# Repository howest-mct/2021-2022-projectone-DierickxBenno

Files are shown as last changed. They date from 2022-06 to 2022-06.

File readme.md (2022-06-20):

# ***Project One - DogBit***

# **Inhoud**

# Getting things ready for Project One 🎉 🎊

- ### Getting things ready for Project One 🎉 🎊

  - ### Installation

    - ### Downloading the image ⏳
    - ### Restoring the image ⏳
    - ### Linking the RasPi
    - ### Preparing raspi for further use

  - ### Configuration

    - ### ⚠ Do it yourself: Provide WiFi access on the RasPi for home use:
    - ### Already done: Full update/upgrade on 5 May 2022, if you want to upgrade, please
    - ### follow the list below:
    - ### Already done: Installing Apache
    - ### Already done: MariaDB

      - ### Already done: Installing MariaDB
      - ### Already done: Securing MariaDB
      - ### Already done: Create MariaDB User

    - ### ⚠ Do it yourself: Configure MySQLWorkbench
    - ### ⚠ Do it yourself: Configure Visual Studio :
    - ### ⚠ do it yourself: GitHub repo cloning:
    - ### Already done: Python ready:
    - ### Already done: Database import:
    - ### Already done: Chromium kiosk:
    - ### ⚠ do it yourself: run app.py:
    - ### ⚠ do it yourself: display front end in Apache.
    - ### ⚠ Do it yourself: When your project is finished, start automatically.

- ### Good luck!
- ### Demo project

# Installation

> During this installation you will download, install and configure the image for ProjectOne. After
> this, you will configure a preinstalled project so that you have a fully functioning front-end and
> backend at the end.

## Downloading the image ⏳

- Download [project_one.img.zip](https://studenthowest-my.sharepoint.com/:u:/g/personal/pieter-jan_beeckman2_howest_be/EZJTscmkyydAj-VcWTAYtjsBiidK5Grxy54ltO-FoOeE2w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)
  to your local computer.

## Restoring the image ⏳

- ### ⚠ Unzip the file ⚠
- ### Place the file on an SD card of at least 8GB with Win32 Imager or Balena Etcher.
- ### After the image is written, you can remove the SD card and insert it into your RasPi.

## Connecting RasPi

- ### Boot your RasPi.
- ### Connect the RasPi to your computer with a network cable and make an SSH connection in Putty. to 192.168.169 for the user student with password W8w00rd.

> ATTENTION: The image has been created in AZERTY (as opposed to Sensors & Interfacing!)
> Should you have trouble logging in, try in qwerty Z! zààrd.

## Preparing raspi for further use

- ### After logging in, tap sudo raspi-config.
- ### In the menu choose (6) Advanced > (1) Expand Filesystem
- ### ⚠ REBOOT de Raspi

> ⚠ ATTENTION: All buses are still deactivated. Do not forget to activate them via raspi- config

# Configuration

## ⚠ Do it yourself: Provide WiFi access on the RasPi for home use:

- sudo -i to get administrator rights

- `wpa_passphrase <your_SSID@Home> <your_wifi password> >> /etc/wpa_supplicant/wpa_supplicant.conf`
  Replace <your_SSID@Home> with the name of your home network and <your_wifi password>
  with the corresponding password.
- wpa_cli -i wlan0 reconfigure to reload your wireless network card in the RasPi.
- wget [http://www.google.com](http://www.google.com) to see if the wireless internet works.

## Already done: Full update/upgrade on 5 May 2022, if you want to upgrade, please follow the list below:

- apt update to check which updates are available.
  (you still have sudo rights from the previous step, so no need to set sudo)
- apt upgrade to install the available updates.
- Y if you are asked if you are sure.
- Waiting, waiting, waiting, ...

## Already done: Install Apache

- apt install apache2 -y to install Apache, the web server. This package takes over for Full Stack
  Web Developlent / ProjectOne from the Live Server in Visual Studio Code.
- As we are working with Github in this exercise we will make it easy for ourselves by
  put all the material in one folder, both front-end and back-end, as we are used to doing in the
  Full Stack Web Development lessons. For this we will have to change Apache's default folder,
  along with the folder and file permissions, but we will only do this once we have created our
  folder structure.

## Already done: MariaDB

### **Already done: Installing MariaDB**

- apt install mariadb-server mariadb-client -y to install MariaDB, the fork of MySQL

### **Already done: Securing MariaDB**

- mysql_secure_installation to better secure the MariaDB
- First you are asked to enter the current root password for MariaDB. Since there is none yet, you
  can just press Enter here.
- Then you can change the password. Choose a password that you can remember! By default, the
  password chosen here is W8w00rd
- The next step is to delete anonymous users. Choose y here
- Prohibit root from logging in remotely. Choose y here.
- Then remove test database and access? Choose y.
- Finally, reload privilege databases: y

### **Already done: Create MariaDB User**

- Next, we configure the user student with password W8w00rd on the MariaDB server.
- mysql -u root -p to access the MariaDB server^
- grant all on `*.*` to `'student'@'localhost'` identified by `'W8w00rd'`; grant grant option on
  `*.*` to `'student'@'localhost'`; Creates a new user _student_ with password _W8w00rd_ who gets rights to all databases.
- `flush privileges` Reloads privileges
- `exit` exits from the MariaDB server

## ⚠ Do it yourself: Configure MySQLWorkbench

- ### Start MySQLWorkBench on your laptop
- ### Create a new connection.
  - ### Under Connection Method, select Standard TCP/IP over SSH.
  - ### SSH Hostname: 192.168.168.
  - ### SSH Username: student
  - ### SSH Password: W8w00rd
  - ### Save this if possible.
  - ### MySQL Hostname: 127.0.0.
  - ### MySQL Server Port: 3306
  - ### Username: student
  - ### Password: W8w00rd Save this if possible.

## ⚠ Do it yourself: Configure Visual Studio:

- Open Visual Studio
- Install the extension Remote-SSH
- Press F1 and tap SSH. Select the option Remote-SSH: Add New SSH Host
- Tap ssh student@192.168.168.169 - A
- Choose a way to save the file.
- Press F1 and tap SSH. Select the option Remote-SSH: Connect To Host
- Choose the option 192.168.
- A new window will open and the password for the RasPi will be requested.
- Type W8w00rd
- After this Visual Studio Codede connection will open and install a number of things on the RasPi.
  > Be patient. It takes a little longer the first time.

## ⚠ do it yourself: GitHub repo cloning:

- Press the Source Control logo on the left and choose Clone Repository.
- Go to the GitHub Classroom [https://classroom.github.com/a/F6MHgLx-] in a browser and
  accept the invitation. Refresh the page and go to the repo you created. Click the Code
  button and copy the git link.
- Paste the copied link into Visual Studio Code and press enter.
- Place the repo in the /home/student/ folder.
- Visual Studio Code will then ask to open this repo, click Yes
- Then open the file Code/Backend/app.py and give Visual Studio Code some time to load all the
  necessary things.

## Already done: Python ready:

- Before we can run the app.py we need to install some packages for python.
- We are NOT using venv here on the RasPi. Open a Terminal and type the following code:
  - pip install flask-cors
  - pip install flask-socketio
  - pip install mysql-connector-python
  - pip install gevent
  - pip install gevent-websocket
- There **_might_** be an easier way to do this with python

## Already done: Database import:

- Import the database into MariaDB via MySQLWorkbench.

## Already done: Chromium kiosk:

- We can make chrome start up by itself, but to do this we need to install a few pieces of software:

  - `pip install selenium`
  - `sudo apt install chromium-chromedriver`

- With selenium we can control the chrome browser (clicks, tab changes, text input), ...

## ⚠ do it yourself: run app.py:

- Try to run app.py. If you can't press Play (the green triangle) in the window, look in the extensions
  under the Python extension and click install on 192.168.168.169 and wait. Reload if asked.
- If all went well, the backend should now be running.

## ⚠ do it yourself: display front end in Apache.

- Surf on your PC to http://192.168.168.169.

- Normally, you should now see the Apache2 Debian Default Page , which is the default Apache
  page currently located in the /var/www/html/ folder on the RasPi. We will not use this default
  folder, but will use the front-end folder from the repo you just cloned.

- If you are no longer sudo: sudo -i

- `nano /etc/apache2/sites-available/000-default.conf`

- Use down arrow to go to the line where it now says _DocumentRoot /var/www/html_
  or _DocumentRoot /home/student/<name_of_your_repo>/front-end_ and change it to _DocumentRoot
  /home/student/<name_of_your_repo>/front-end_
- Save by doing _Ctrl + x_ , followed by Y and _Enter_
- Then we restart Apache by doing `service apache2 restart`
- Now we have to set the permissions on the root folder correctly.

  - Open nano /etc/apache2/apache2.conf and use the down arrow to look for the following
    lines:

    > ```
    >  <Directory />
    >  Options FollowSymLinks
    >  AllowOverride All
    >  Require all denied
    >  </Directory>.
    > ```

    and change it to:

    > ```
    > <Directory />
    > Options Indexes FollowSymLinks Includes ExecCGI
    > AllowOverride All
    > Require all granted
    > </Directory>.
    > ```

  - Save by doing _trl + x_ , followed by Y and _Enter_

  - Then restart Apache by doing service `apache2 restart`

  - Check if apache is started correctly: `service apache2 status`.
    You should get approximately the following output:

  > Loaded: loaded (/lib/systemd/system/apache2.service; enabled; vendor preset:
  > enabled)
  > Active: active (running) since ...

## ⚠ Do it yourself: When your project is finished, start automatically.

- Create a file called myproject.service
- Place the following code in the file:

  ```
  [Unit]
  Description=ProjectOne Project
  After=network.target
  [Service]
  ExecStart=/usr/bin/python3 -u /home/student/<name_of_your_repo>/backend/app.py

  WorkingDirectory=/home/student/<name_of_your_repo>/backend
  StandardOutput=inherit
  StandardError=inherit
  Restart=always
  User=student
  [Install].
  WantedBy=multi-user.target
  ```

- Copy this file as root user to `/etc/systemd/system` with the command `sudo cp myproject.service/etc/systemd/system/myproject.service`
- Now you can test the file by starting it: sudo systemctl start myproject.service
- Stopping the file can be done by entering the command: sudo systemctl stop myproject.service
- If everything works well you can have the script start automatically after booting: `sudo systemctl enable myproject.service`
- The logs / console output can be seen via `journalctl -u myproject.service`

## Good luck!

> If everything works out, don't forget to take a selfie and submit it to the appropriate assignment!

# Demo project

The image shows an example project where we link a button and LED in real time to the website
and database

- First follow the steps in Installation and Configuration
- Connect a button to pin 20 (use safety resistor)
- Also connect a LED to pin 21 (don't forget its resistor)
- Start via terminal backend:
  > ```
  > cd ~/projectone-demo/backend/
  > python app.py
  > ```
- We will skip apache for a while and will also use python to serve the front-end. In a second
  terminal:
  > ```
  > cd ~/projectone-demo/front-end/
  > python -m http.server
  > ```
- Now you can go to http://192.168.168.169:8000

- The idea now is to get this code into your own repo
- So make sure that your own repo is cloned in `/home/student/<name_of_your_repo>`.

- We will copy the files to our repo:

  > `cp -r ~/projectone-demo/* /home/student/<name_of_your_repo>/`

      - So in my case this is `cp -r ~/projectone-demo/* /home/student/2021-2022-projectone-fgmnts/`

- When you have done this, make sure that apache is configured to display the front-end. The
backend code can be executed manually during development, but for production make sure
the code is started automatically via the service

- Make sure you commit and push your new code, this is the command for the kickoff on 20/

# **Instructables**

https://www.instructables.com/Dog-Health-Tracking-Device-the-DogBit/

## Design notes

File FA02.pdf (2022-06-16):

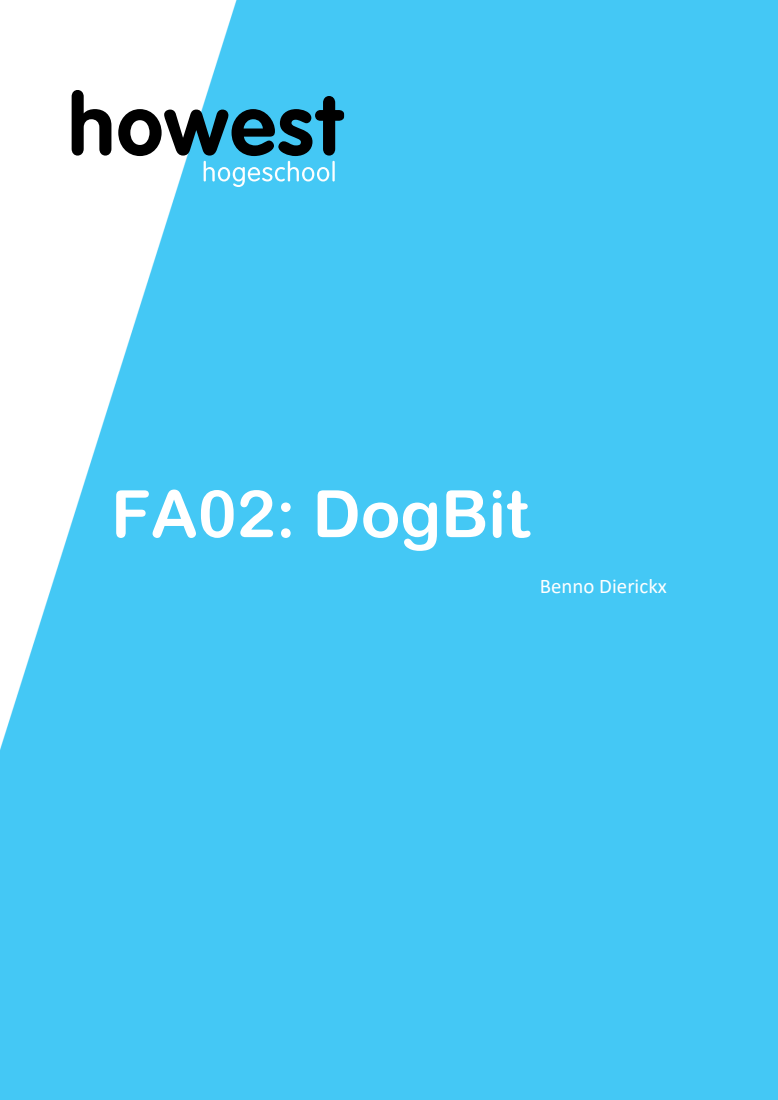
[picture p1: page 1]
FA02: DogBit; Benno Dierickx

## Table of Contents

FA02+designdoc 3

Functioneel Ontwerp

Probleemstelling
Hondeneigenaars zijn vaak bezorgd over de gezondheid van hun huisdier: beweegt mijn hond te weinig of net te veel, drinkt hij voldoende, heeft hij een gezonde hartslag?

Het is moeilijk om in te schatten of de hond voldoende beweging en voldoende vocht krijgt. Beide zijn nodig voor een goede gezondheid de hond. Voor jonge honden is het bijvoorbeeld belangrijk om de beweging langzaam op te bouwen. Een puppy van 10 weken mag wandelingen maken van maximum 10 minuten. Daar mag elke week één minuut bij. Als jonge honden te snel grote wandelingen maken, kan dat op latere leeftijd problemen geven aan hun gewrichten. Oudere honden mogen dan weer niet te passief worden. Daar is het belangrijk om na te gaan of ze wel voldoende beweging krijgen. Ook voor honden met overgewicht is het nuttig en nodig om meer te bewegen en dit op een verantwoorde manier te doen. Tenslotte zijn er ook honden die trainen voor een bepaalde sport. Ook hun parameters moeten goed opgevolgd worden om overtraining en gewrichtsproblemen te voorkomen.

Een gezonde hond heeft een hartslag van 60-120 slagen per minuut (kleine rassen hebben een normale frequentie tussen de 90 en 120, grote rassen tussen de 60 en 90). Als de hond slaapt, kan de hartslag dalen naar 30 slagen per minuut. Bij het inspanning of opwinding mag de hartslag hoger dan 120 worden. Voor een hondeneigenaar het moeilijk om zelf de hartslag te meten.

Honden zijn gevoelig voor warmte. Zij moeten bij warme temperaturen rustiger aandoen en meer vocht opnemen. Ook hier is dit voor de baasjes moeilijk in te schatten. De normale lichaamstemperatuur van de hond is tussen de 38 en 39°C. Maar bij buitentemperaturen boven 25°C kan de temperatuur van de hond oplopen tot 41°C en kan de hond een ‘hitteslag’ krijgen en zelfs in shock gaan.

Tenslotte is er ook een probleem dat niet zozeer met de gezondheid van de hond te maken heeft, maar wel met de veiligheid. Veel hondenbaasjes kunnen pas ’s avonds gaan wandelen als het schemert of al donker is. Als de hond en het baasje in het donker wandelen, zijn ze slecht zichtbaar en dat is natuurlijk gevaarlijk.

Oplossing
De oplossing is een harnas dat de verschillende parameters kan meten en registreren. Het harnas geeft een bericht als bepaalde grenzen overschreden zijn. De hond moet dan meer of minder bewegen, of vocht opnemen. een manier vinden om door middel van sensoren de snelheid, stappen, hartslag en vochtopname van de hond te meten.
Daarnaast zijn er ook sensoren nodig die de temperatuur en de het licht kunnen meten.

Projectresultaat
Ik ga een harnas voor honden maken dat functioneert als fitness-tracker voor honden en met een bijkomende functionaliteit die aangeeft wanneer het donker wordt.
In de responsieve webapp kan je de hartslag op het moment zelf bekijken, het aantal stappen bekijken, gemiddelde snelheid, afgelegde afstand en historiek. Je kan ook zien welke route je hebt afgelegd/wilt afleggen met behulp van de GPS. Verder wordt de lichtintensiteit ook gemeten om de LEDS aan te sturen, aan de hand van de temperatuur sensor en de ECG zal er een melding gestuurd kunnen worden wanneer de hond best water krijgt.

De esp32 functioneert als Master voor de sensoren en geeft actief de gemeten data weer.
Aangezien de esp32 slechts 4MB flash memory heeft, zal recente data opgeslagen worden op het device waarmee hij verbonden is, het device stuurt deze data dan door naar de webapp. Als de esp32 zelf kan verbinden met een netwerk zal hij dit doen en de data rechtstreeks naar de Raspberry sturen.
De Raspberry houdt de data bij in een sql database.

Wanneer de LDR een lage licht intensiteit meet gaan er LEDS op het harnas aan, de kleur en saturation kunnen aangepast worden de saturatie wordt bepaald door de lichtintensiteit. (HSB)

Merk op: moest starlink heel België dekken dan zou ik meer kunnen doen met locatie. Want dan kan de esp32 verbinden met de webserver over heel België.

Functionele eisen
Behuizing:
3D printen voor houders van de componenten
Elektronica:
one-wire temp sensor, GPS, gyroscoop, ECG (hartslagsensor), LEDs (WS2812B, word aangestuurd met een enkele datalijn (D in en D out, kunnen op elkaar aangesloten worden, komt overeen met een strip met meer LEDs/neon pixels)).
Datacaptatie:
Snelheid, locatie, hartslag, tijd (om bpm van hartslag te berekenen), omgevingstemperatuur, lichtintensiteit.
Visualisatie:
Er wordt een historiek bijgehouden van de datacaptatie, behalve licht intensiteit. De gemiddelde waardes worden ook bijgehouden.
SQL database:
Datum, duur van de wandeling, aantal stappen tijdens de wandeling, gemiddelde hartslag, gemiddelde snelheid, omgevingstemperatuur
Webserver:
De data die de esp32 meet wordt door gestuurd naar de Raspberry, de Raspberry stuurt de tijd door naar de esp32 (nodig voor bpm en duur wandeling).

Blokschema

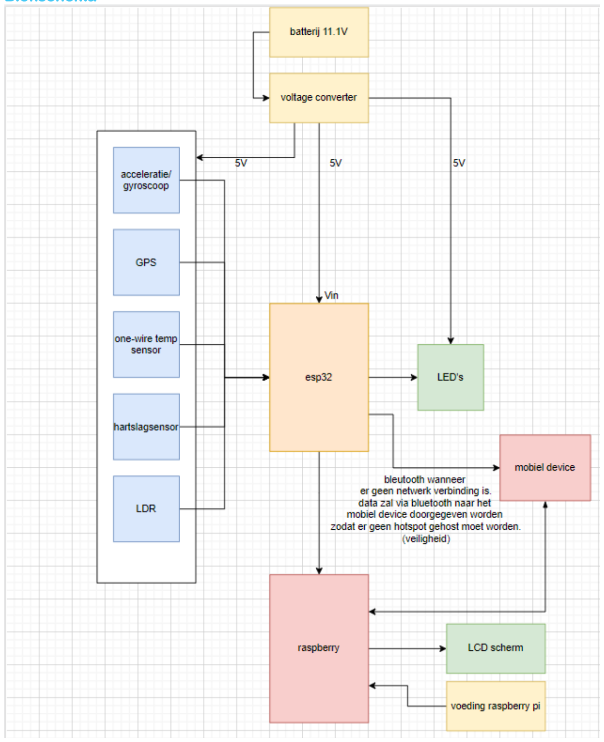
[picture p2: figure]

Doelgroep
De doelgroep voor de DogBit zijn hondeneigenaars die bekommerd zijn over de gezondheid van hun hond en dit ook goed willen opvolgen. Het zijn mensen die dagelijks wandelen met hun hond en dat op een gezonde manier willen doen: niet te veel en niet te weinig, met oog voor de temperatuur en de veiligheid.

Bij millennials is het bijna een rage om een hond te nemen en die te behandelen als een kind. De markt van hondenspeeltjes, hondenvoeding, hondenmandjes en verzorgingsproducten speelt daar enorm op in. Er zijn ook steeds meer hondenscholen en hondensporten. De doelgroep zijn dan ook mensen die tijd en geld willen investeren in hun hond. Deze DogBit is allicht iets dat deze doelgroep kan interesseren.

Concurrentie analyse
functionaliteiten | petPace (https://petpace.com/) | fitbarkGPS (https://www.fitbark.com/store/fitbarkGPS/) | kippy-vita (https://www.kippy.eu/en/service-package) | Weenect (https://www.weenect.com/nl/)
24/7 activity monitoring | Ja | Ja | Ja | Ja
Linken met Fitbit, Apple healthkit, … | Nee | Ja | Nee | Nee
Gps tracking | Nee | Ja | Ja | Ja
abonnement | Ja (in begrepen in de aankoop prijs, 4 jaar geldig) | Ja (prijs niet duidelijk) | Ja (3-10euro) | Ja (9,99€/maand)
waterdicht | IPx7 | IP67 | spatwaterdicht | IP67
Calorie verbruik opvolgen | Ja | Ja | Ja | Nee
Meldingen bij gedragsverandering | Ja | Ja | nee | Nee
doelstellingen | Nee | Ja | Ja | Nee
Ziekte opsporing | Ja (core functionaliteit) | Ja | Nee | Nee
bluetooth | Nee | Ja | Nee | Nee
geoFence (safe zone alerts) | Nee | Ja | Ja | Ja
Actieve kaart | Nee | Ja | Ja | Ja
Routes opslagen | Nee | Nee | Ja | Ja
Eigenaars, vrienden en dieren artsen toevoegen. | Ja (artsen) | Ja | Nee | Ja
Ingebouwde LED lamp (voor zichtbaarheid dier) | Nee | Nee | Ja | Nee
Batterij leven | Meer dan 3 weken | 10-20 dagen | 16 dagen | 3 dagen
Hartslag | Ja | Nee | Nee | Nee
Lichaams temperatuur | Ja | Nee | Nee | Nee
Positie (houding) | Ja | Nee | Nee | Nee
ademhaling | Ja | Nee | Nee | Nee
Heart Rate Variability (HRV) | Ja | Nee | Nee | Nee

CONCLUSIE
De PetPace is een tool die enorm veel gezondheidsparameters van een hond meet. De kippa Vita en Weenect zijn dan weer vooral trackers, die de wandelingen registreren en die de locatie van de hond bepalen. De fitBarkGPS zit er ergens tussenin.

De DogBit verschilt van deze tools omdat het aantal parameters beperkt is tot de meest nuttige voor gezonde honden. De DogBit is vooral nuttig voor eigenaars die regelmatig wandelen met hun hond en de afstand en intensiteit van de wandeling willen afstemmen op de noden van de hond en op de buitentemperatuur.

Bronnen:

Over hartslag van de hond:
- De hartslag bij de hond (https://mcvoordieren.nl/kennisbank/hartslag-hond/)
- Pols - hartslag opnemen (https://www.dierendokters.com/honden/hoe-doe-ik-dit/pols-hartslag-opnemen)
- Hartslag, ademhaling en temperatuur bij honden (https://huisvee.nl/hartslag-ademhaling-en-temperatuur-bij-honden/)

Hitteslag bij hond:
- oververhitting (https://www.daphetneerhof.be/jouw-dier/hond/oververhitting)

Alles over bewegen met de hond:
- https://www.dogline.nl/hoeveel-beweging-heeft-een-hond-nodig/
- https://www.dierapotheker.nl/dierentips/hoe-vaak-hond-uitlaten

Taakanalyse
- Historiek bekijken:
Parameter(s) kiezen
Tijds periode kiezen
- Kleur LEDs aanpassen:
Hue aanpassen in kleuren wiel (wit kan ook als kleur gekozen worden),
Hue doorsturen naar esp,
In de esp word op basis van de lichtintensiteit de RGB waarde bepaald (saturatie wijzigt)
- Melding sturen wanneer er water gedronken moet worden: Activiteit bepalen (gem snelheid, …)
Omgevingstemperatuur bepalen
tijdsduur
op basis van deze wordt er bepaald wanneer er water gedronken moet worden
- Melding sturen bij bereiken doelstelling bereikt Leeftijd van hond bepalen (vooral puppy’s)
(gekozen) doelstelling bepalen
Melding wanneer activiteitsdoel behaald is.

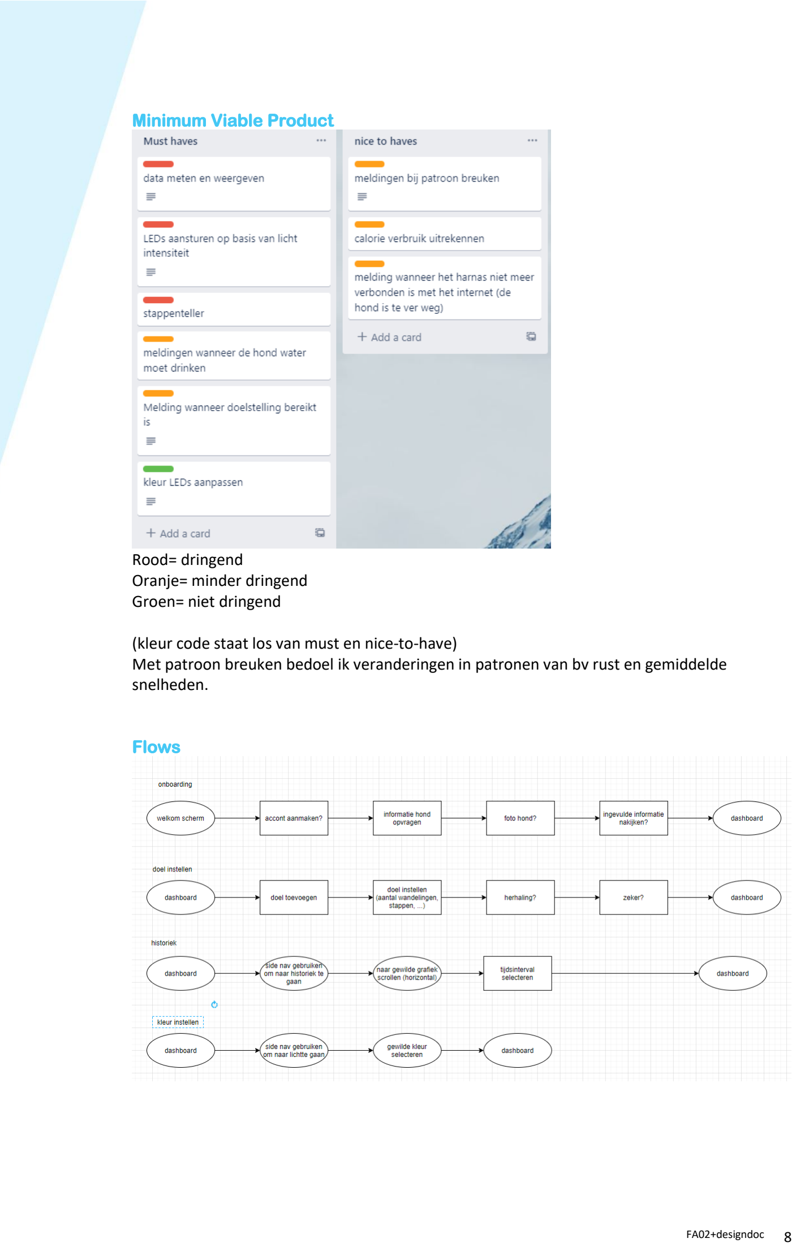
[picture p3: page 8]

Minimum Viable Product

Rood= dringend
Oranje= minder dringend
Groen= niet dringend

(kleur code staat los van must en nice-to-have)
Met patroon breuken bedoel ik veranderingen in patronen van bv rust en gemiddelde snelheden.

Flows

Wireframes

Testresultaten
Uit de testen bleek dat de site goed gedesigned was en dat er een minimum van aanpassingen moest gebeuren

Er is een scrollbar nodig bij de colorpicker

Er gaat een scrollbar aanwezig zijn in de html file (automatisch, uit mijn weg gaan om dit uit te zetten zou onnodig zijn)

Design document

Inspiratie
https://dribbble.com/shots/13662178-Gradientshttps://dribbble.com/shots/15076348-Pet-it-Online-pet-storehttps://dribbble.com/shots/15640260-Web-UI-Project-Management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

Kleurschema
Deze kleuren zijn gebruikt geweest in de xd file

#FFF: achtergrond html en letters met donkere achtergrond #DDE: achtergrond info blokken

#436BF2: navigatie achtergrond

#2655FB: achtergrond titel

#38434A: grijswaarde die als achtergrond voor sommige teksten dient en de kleur van sommige teksten #888: als box-shadow kleur

Contrast test
Waarde op waarde holder

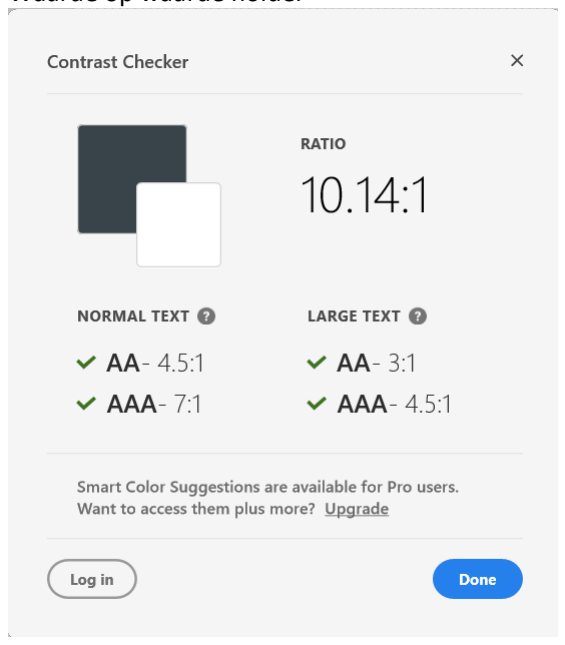
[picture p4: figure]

Titel (grote tekst)

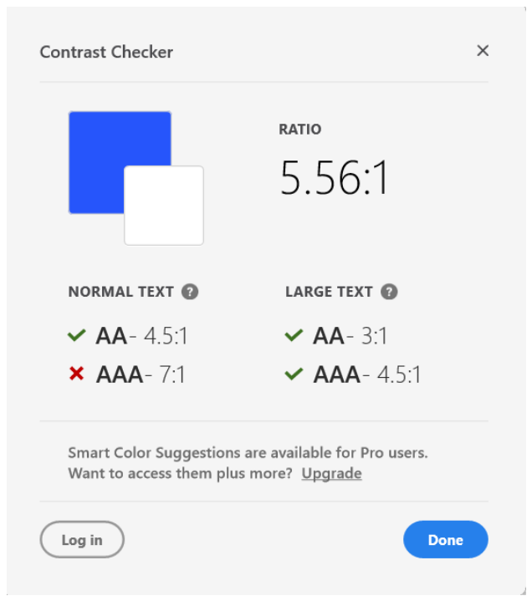
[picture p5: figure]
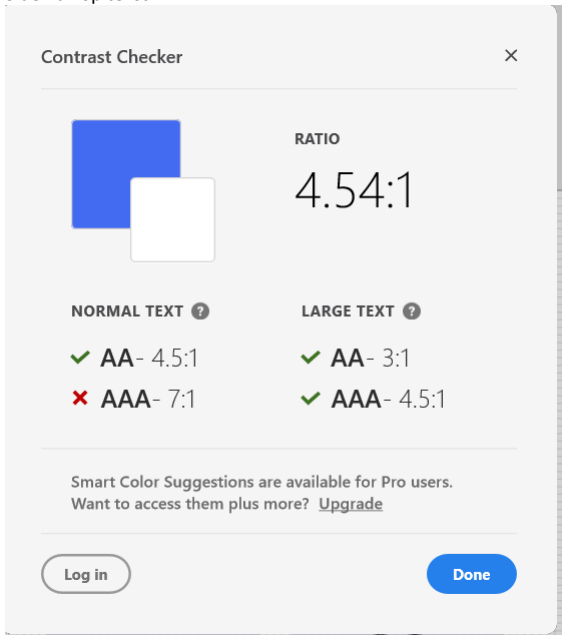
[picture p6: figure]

Side nav op tekst

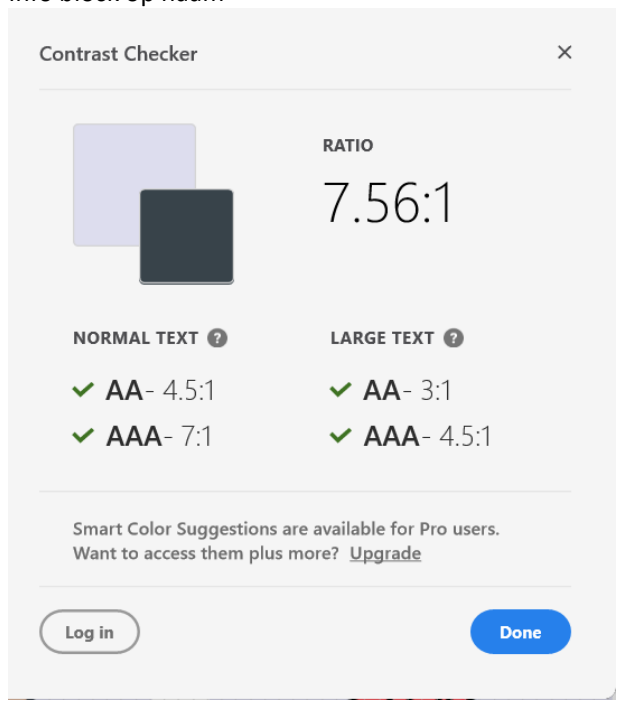
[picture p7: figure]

Info block op naam

Typografie

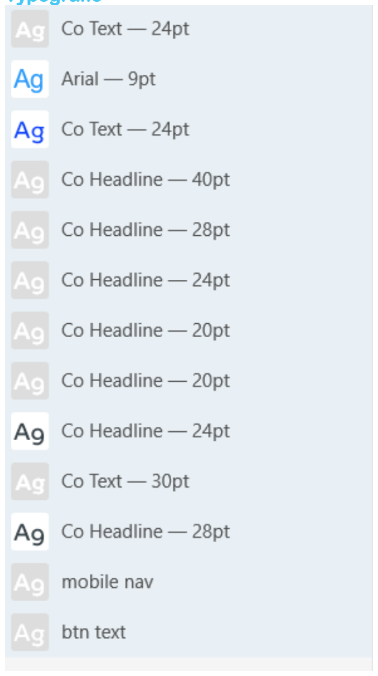
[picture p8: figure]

Co: adobe fonts

Icons
https://icons8.com/
https://img.icons8.com/cotton/64/undefined/dog-jump--v1.pnghttps://img.icons8.com/external-nawicon-outline-color-nawicon/64/undefined/external-heartbeat-medical-nawi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 (https://img.icons8.com/external-nawicon-outline-color-nawicon/64/undefined/external-heartbeat-medical-nawicon-outline-color-nawicon.png)
https://img.icons8.com/dusk/64/undefined/running-away.pnghttps://img.icons8.com/office/16/undefined/temperature--v1.png

deze zijn “free for a link” de links staan ook in het html bestand

Bronnen
https://icons8.com/
https://fonts.adobe.com/
https://fonts.google.com/

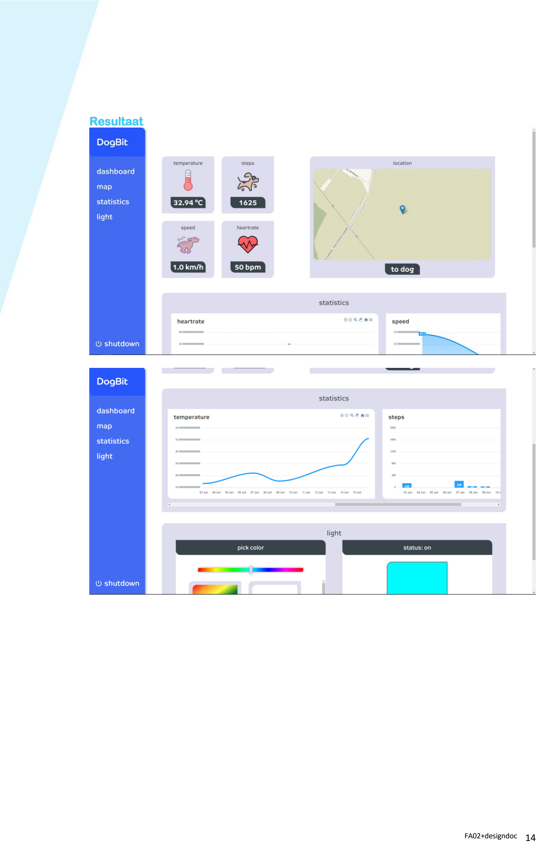
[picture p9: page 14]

Resultaat

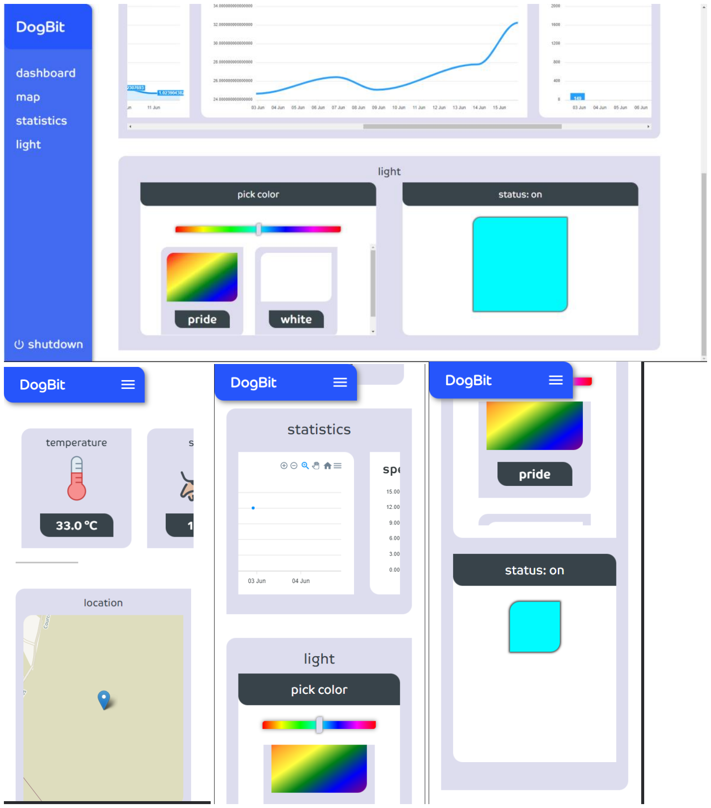
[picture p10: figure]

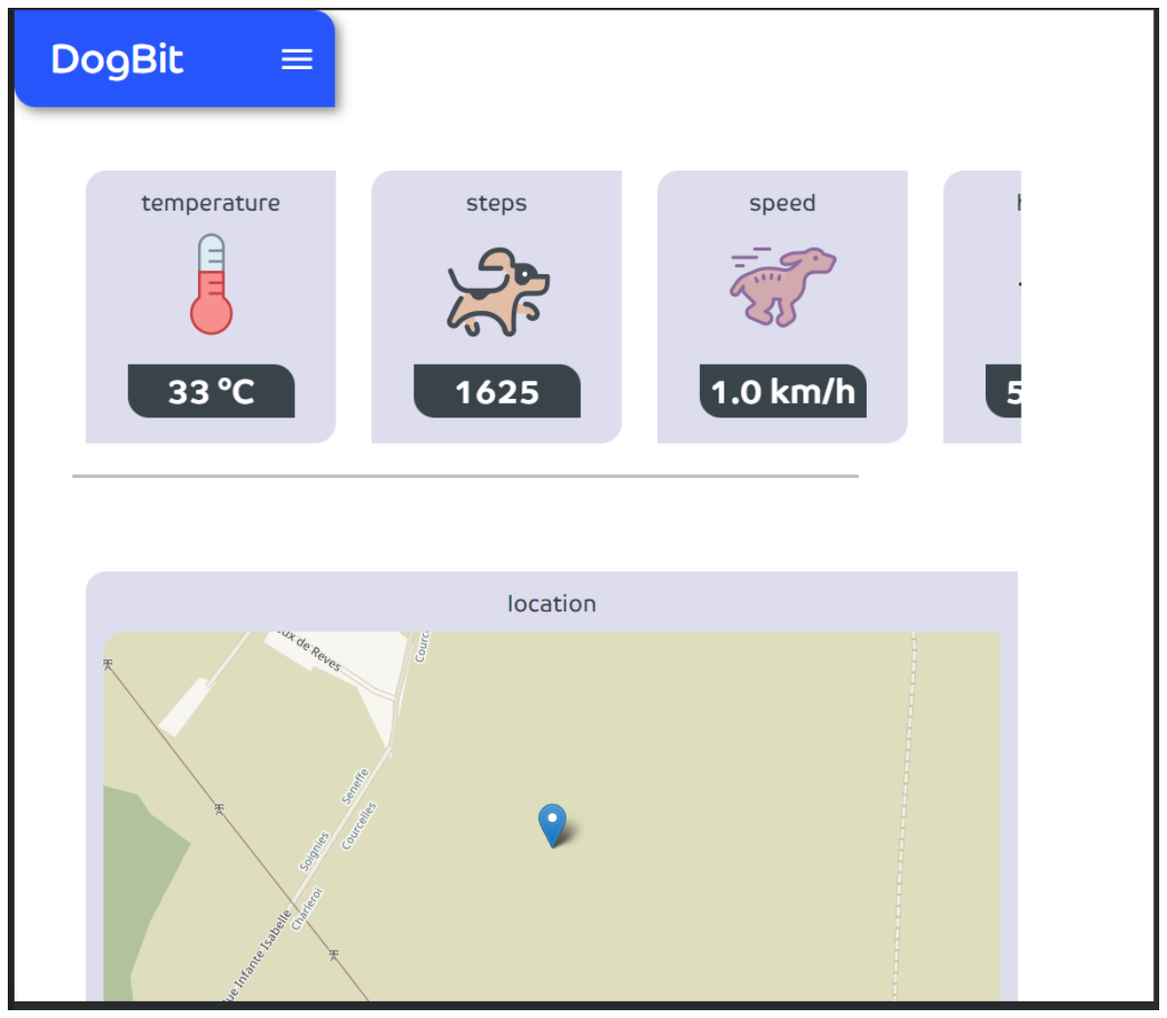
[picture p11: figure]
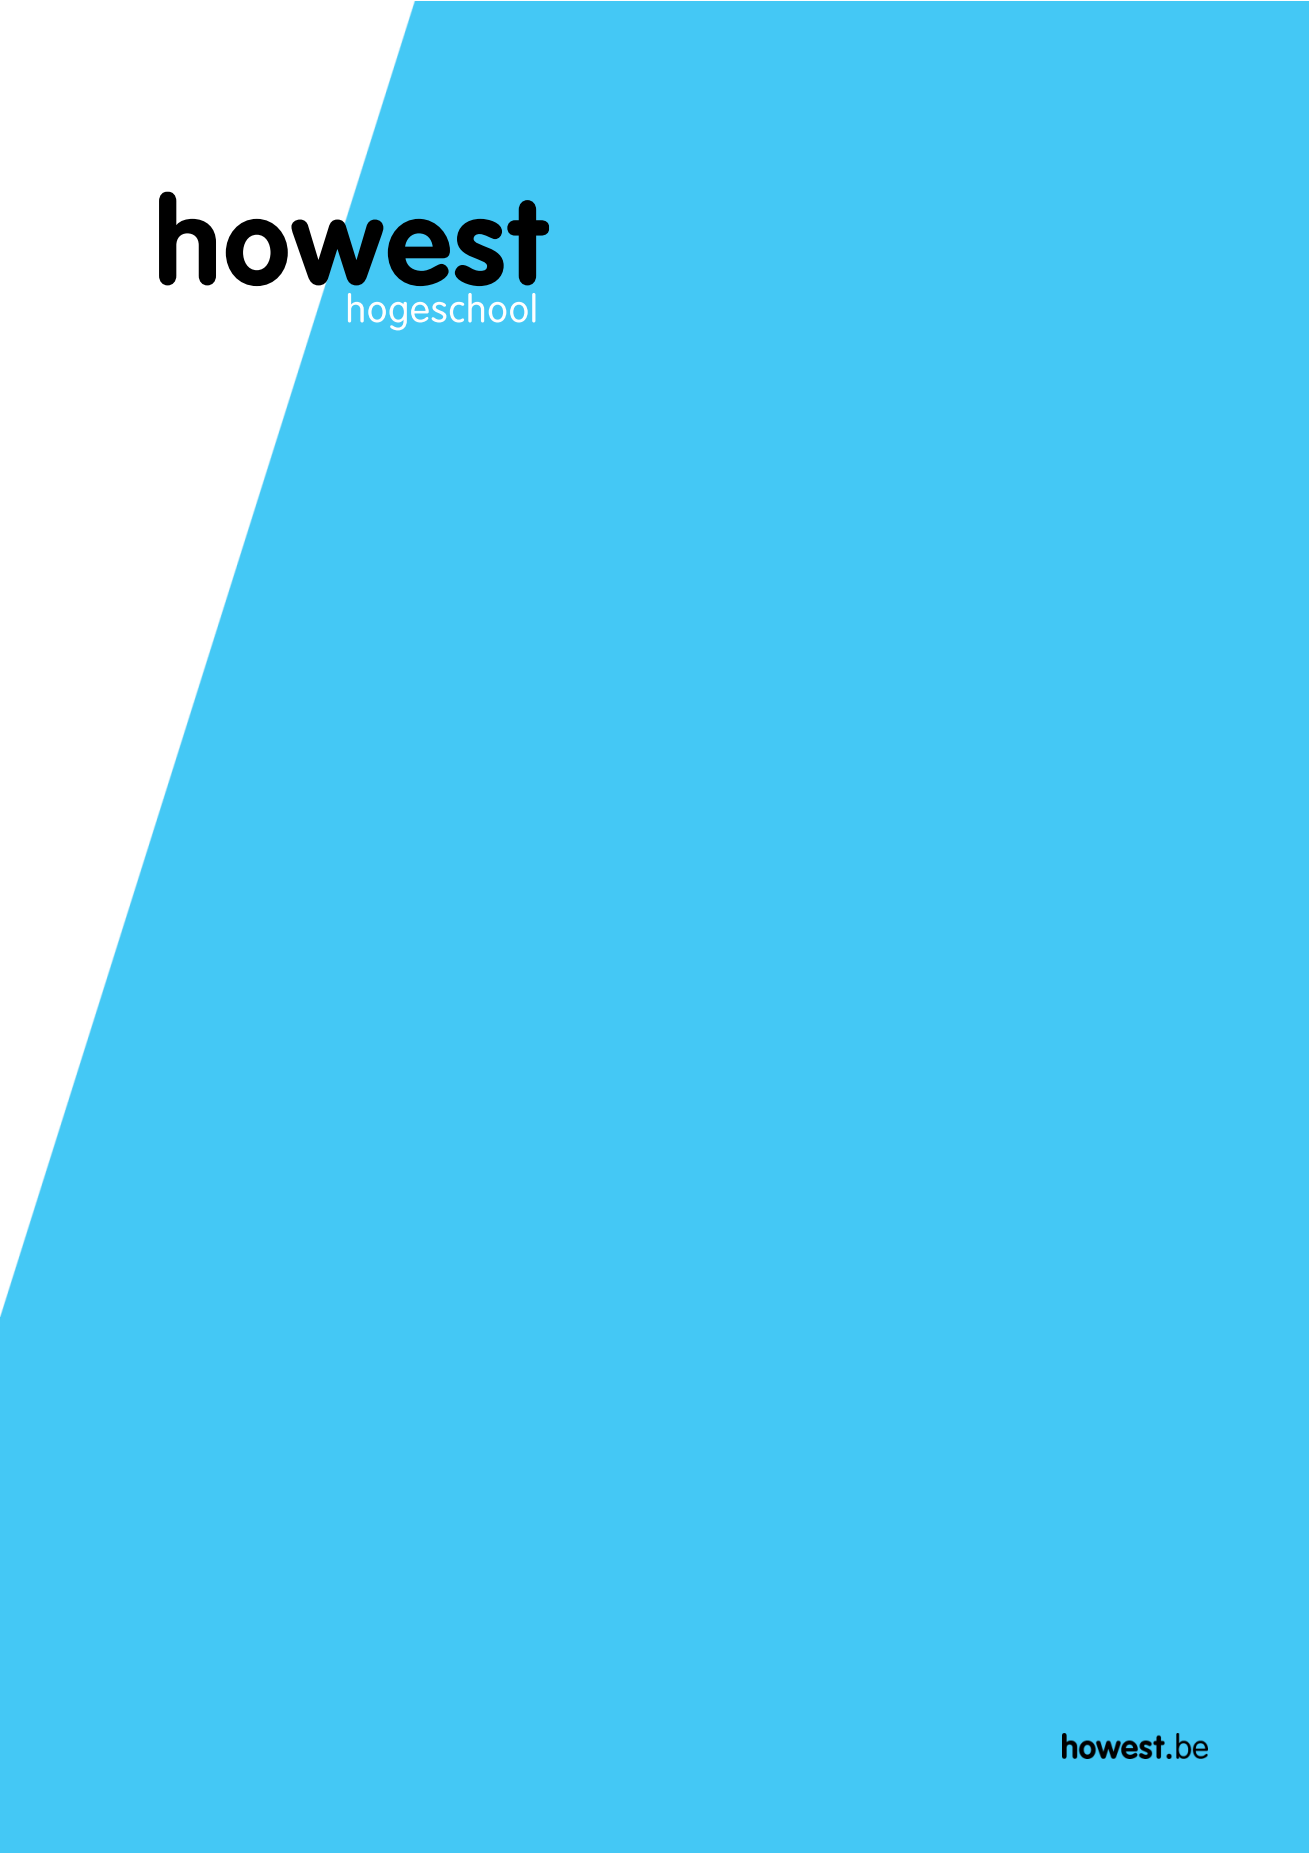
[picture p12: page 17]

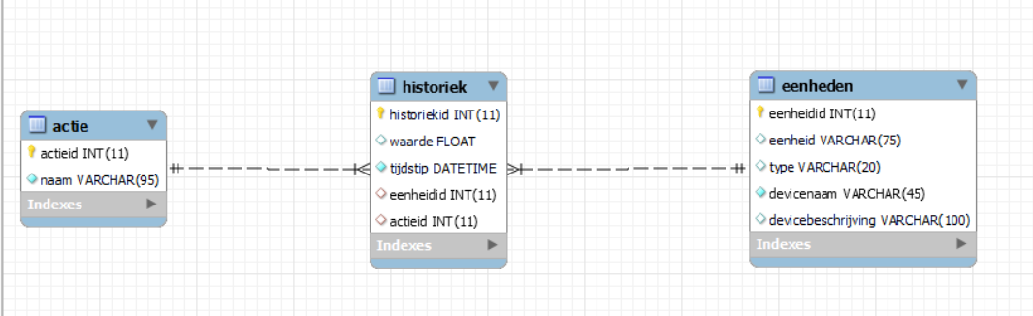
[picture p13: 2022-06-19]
database-export/EERD.PNG

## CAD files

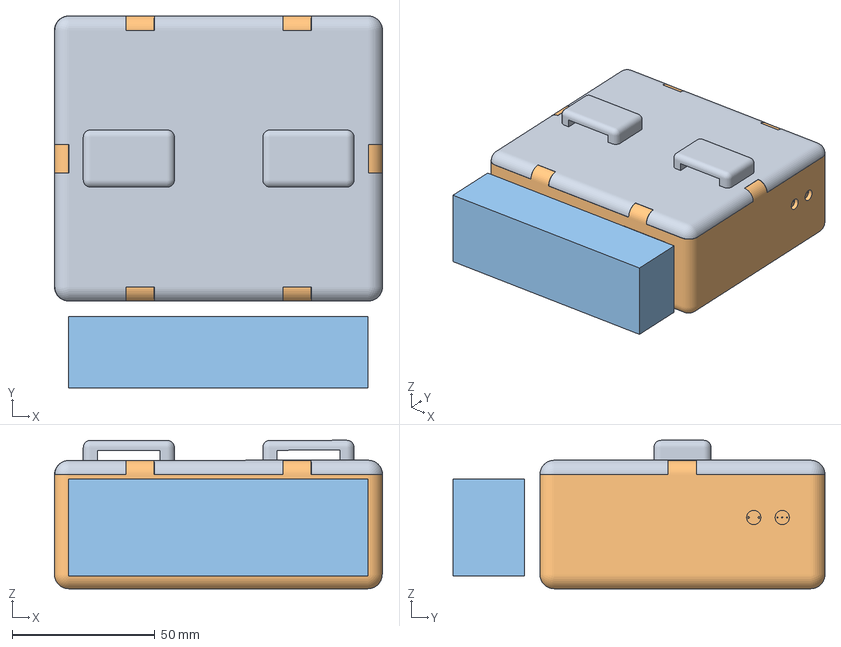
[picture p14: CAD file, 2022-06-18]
doos v26.3mf
115.1 x 130.5 x 52.1 mm

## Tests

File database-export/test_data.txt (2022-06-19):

1	1	2022-06-09 03:36:05	2	NULL
2	4.854887564	2022-06-09 03:36:35	4	NULL
3	4.32966021	2022-06-09 03:37:05	4	NULL
4	50.7005438	2022-06-09 03:37:35	3	NULL
5	30	2022-06-09 03:38:05	7	NULL
6	4.078209445	2022-06-09 03:38:35	4	NULL
7	1	2022-06-09 03:39:05	2	NULL
8	51.20973974	2022-06-09 03:39:35	3	NULL
9	50.39812764	2022-06-09 03:40:05	3	NULL
10	0	2022-06-09 03:40:35	1	NULL
11	1	2022-06-09 03:41:05	2	NULL
12	50.91742878	2022-06-09 03:41:35	3	NULL
13	51.28410466	2022-06-09 03:42:05	3	NULL
14	51.11086336	2022-06-09 03:42:35	3	NULL
15	1	2022-06-09 03:43:05	2	NULL
16	1	2022-06-09 03:43:35	2	NULL
17	30	2022-06-09 03:44:05	7	NULL
18	23	2022-06-09 03:44:35	7	NULL
19	50.99338562	2022-06-09 03:45:05	3	NULL
20	24	2022-06-09 03:45:35	7	NULL
21	51.1314616	2022-06-09 03:46:05	3	NULL
22	4.494431181	2022-06-09 03:46:35	4	NULL
23	1	2022-06-09 03:47:05	2	NULL
24	43	2022-06-09 03:47:35	1	NULL
25	4.369580962	2022-06-09 03:48:05	4	NULL
26	50.87499206	2022-06-09 03:48:35	3	NULL
27	1	2022-06-09 03:49:05	2	NULL
28	80	2022-06-09 03:49:35	5	NULL
29	29	2022-06-09 03:50:05	7	NULL
30	79	2022-06-09 03:50:35	6	NULL
31	31	2022-06-09 03:51:05	7	NULL
32	32	2022-06-09 03:51:35	7	NULL
33	1	2022-06-09 03:52:05	2	NULL
34	110	2022-06-09 03:52:35	5	NULL
35	50.50363642	2022-06-09 03:53:05	3	NULL
36	4.480131005	2022-06-09 03:53:35	4	NULL
37	98	2022-06-09 03:54:05	5	NULL
38	4.472015059	2022-06-09 03:54:35	4	NULL
39	4.541808198	2022-06-09 03:55:05	4	NULL
40	88	2022-06-09 03:55:35	5	NULL
41	37	2022-06-09 03:56:05	1	NULL
42	0	2022-06-09 03:56:35	1	NULL
43	73	2022-06-09 03:57:05	6	NULL
44	109	2022-06-09 03:57:35	5	NULL
45	36	2022-06-09 03:58:05	1	NULL
46	104	2022-06-09 03:58:35	5	NULL
47	88	2022-06-09 03:59:05	5	NULL
48	1	2022-06-09 03:59:35	2	NULL
49	50.64469482	2022-06-09 04:00:05	3	NULL
50	31	2022-06-09 04:00:35	7	NULL
51	28	2022-06-09 04:01:05	7	NULL
52	51.07355824	2022-06-09 04:01:35	3	NULL
53	48	2022-06-09 04:02:05	6	NULL
54	30	2022-06-09 04:02:35	7	NULL
55	50.4545413	2022-06-09 04:03:05	3	NULL
56	50.89542849	2022-06-09 04:03:35	3	NULL
57	50.80356307	2022-06-09 04:04:05	3	NULL
58	50.9095837	2022-06-09 04:04:35	3	NULL
59	45	2022-06-09 04:05:05	1	NULL
60	50.86132597	2022-06-09 04:05:35	3	NULL
61	50.67839955	2022-06-09 04:06:05	3	NULL
62	1	2022-06-09 04:06:35	2	NULL
63	50.58028257	2022-06-09 04:07:05	3	NULL
64	21	2022-06-09 04:07:35	1	NULL
65	4	2022-06-09 04:08:05	1	NULL
66	1	2022-06-09 04:08:35	2	NULL
67	3.993146837	2022-06-09 04:09:05	4	NULL
68	1	2022-06-09 04:09:35	2	NULL
69	93	2022-06-09 04:10:05	5	NULL
70	47	2022-06-09 04:10:35	1	NULL
71	31	2022-06-09 04:11:05	1	NULL
72	34	2022-06-09 04:11:35	1	NULL
73	27	2022-06-09 04:12:05	7	NULL
74	80	2022-06-09 04:12:35	5	NULL
75	46	2022-06-09 04:13:05	1	NULL
76	3.917273608	2022-06-09 04:13:35	4	NULL
77	90	2022-06-09 04:14:05	5	NULL
78	1	2022-06-09 04:14:35	2	NULL
79	4.485389945	2022-06-09 04:15:05	4	NULL
80	51.07574779	2022-06-09 04:15:35	3	NULL
81	4.473507837	2022-06-09 04:16:05	4	NULL
82	4.130227719	2022-06-09 04:16:35	4	NULL
83	4.460451962	2022-06-09 04:17:05	4	NULL
84	51.15529765	2022-06-09 04:17:35	3	NULL
85	98	2022-06-09 04:18:05	6	NULL
86	50.7839874	2022-06-09 04:18:35	3	NULL
87	80	2022-06-09 04:19:05	5	NULL
88	22	2022-06-09 04:19:35	7	NULL
89	50.37072334	2022-06-09 04:20:04	3	NULL
90	25	2022-06-09 04:20:34	7	NULL
91	1	2022-06-09 04:21:04	2	NULL
92	3.985287025	2022-06-09 04:21:34	4	NULL
93	91	2022-06-09 04:22:04	5	NULL
94	4.662133782	2022-06-09 04:22:34	4	NULL
95	50.84497384	2022-06-09 04:23:04	3	NULL
96	1	2022-06-09 04:23:34	2	NULL
97	50.9775213	2022-06-09 04:24:04	3	NULL
98	113	2022-06-09 04:24:34	5	NULL
99	16	2022-06-09 04:25:04	1	NULL
100	16	2022-06-09 04:25:34	1	NULL
101	1	2022-06-09 04:26:04	2	NULL
102	1	2022-06-09 04:26:34	2	NULL
103	1	2022-06-09 04:27:04	2	NULL
104	25	2022-06-09 04:27:34	7	NULL
105	89	2022-06-09 04:28:04	5	NULL
106	32	2022-06-09 04:28:34	7	NULL
107	35	2022-06-09 04:29:04	6	NULL
108	21	2022-06-09 04:29:34	1	NULL
109	24	2022-06-09 04:30:04	6	NULL
110	4.695973145	2022-06-09 04:30:34	4	NULL
111	50.91250213	2022-06-09 04:31:04	3	NULL
112	37	2022-06-09 04:31:34	1	NULL
113	27	2022-06-09 04:32:04	7	NULL
114	27	2022-06-09 04:32:34	6	NULL
115	3.904333634	2022-06-09 04:33:04	4	NULL
116	32	2022-06-09 04:33:34	7	NULL
117	4.870015667	2022-06-09 04:34:04	4	NULL
118	38	2022-06-09 04:34:34	1	NULL
119	24	2022-06-09 04:35:04	7	NULL
120	50.37542401	2022-06-09 04:35:34	3	NULL
121	4.65375813	2022-06-09 04:36:04	4	NULL
122	87	2022-06-09 04:36:34	5	NULL
123	47	2022-06-09 04:37:04	1	NULL
124	7	2022-06-09 04:37:34	1	NULL
125	24	2022-06-09 04:38:04	7	NULL
126	4.132393889	2022-06-09 04:38:34	4	NULL
127	4.031546018	2022-06-09 04:39:04	4	NULL
128	97	2022-06-09 04:39:34	5	NULL
129	1	2022-06-09 04:40:04	2	NULL
130	65	2022-06-09 04:40:34	6	NULL
131	11	2022-06-09 04:41:04	1	NULL
132	25	2022-06-09 04:41:34	7	NULL
133	4.208018355	2022-06-09 04:42:04	4	NULL
134	51.00847712	2022-06-09 04:42:34	3	NULL
135	66	2022-06-09 04:43:04	6	NULL
136	4.692649137	2022-06-09 04:43:34	4	NULL
137	1	2022-06-09 04:44:04	2	NULL
138	32	2022-06-09 04:44:34	7	NULL
139	1	2022-06-09 04:45:04	2	NULL
140	0	2022-06-09 04:45:34	1	NULL
141	30	2022-06-09 04:46:04	7	NULL
142	27	2022-06-09 04:46:34	6	NULL
143	50.44784011	2022-06-09 04:47:04	3	NULL
144	103	2022-06-09 04:47:34	5	NULL
145	4.410224169	2022-06-09 04:48:04	4	NULL
146	55	2022-06-09 04:48:34	6	NULL
147	115	2022-06-09 04:49:04	5	NULL
148	71	2022-06-09 04:49:34	6	NULL
149	90	2022-06-09 04:50:04	5	NULL
150	1	2022-06-09 04:50:34	2	NULL
151	85	2022-06-09 04:51:04	5	NULL
152	89	2022-06-09 04:51:34	5	NULL
153	1	2022-06-09 04:52:04	2	NULL
154	81	2022-06-09 04:52:34	6	NULL
155	50.45219303	2022-06-09 04:53:04	3	NULL
156	1	2022-06-09 04:53:34	1	NULL
157	4.091019502	2022-06-09 04:54:04	4	NULL
158	107	2022-06-09 04:54:34	5	NULL
159	50.33316503	2022-06-09 04:55:04	3	NULL
160	1	2022-06-09 04:55:34	2	NULL
161	13	2022-06-09 04:56:04	1	NULL
162	38	2022-06-09 04:56:34	1	NULL
163	107	2022-06-09 04:57:04	5	NULL
164	27	2022-06-09 04:57:34	7	NULL
165	4.645035546	2022-06-09 04:58:04	4	NULL
166	25	2022-06-09 04:58:34	7	NULL
167	0	2022-06-09 04:59:04	1	NULL
168	1	2022-06-09 04:59:34	2	NULL
169	33	2022-06-09 05:00:04	1	NULL
170	50.98109044	2022-06-09 05:00:34	3	NULL
171	4.720081597	2022-06-09 05:01:04	4	NULL
172	4.623532121	2022-06-09 05:01:34	4	NULL
173	1	2022-06-09 05:02:04	2	NULL
174	69	2022-06-09 05:02:34	6	NULL
175	22	2022-06-09 05:03:04	7	NULL
176	1	2022-06-09 05:03:34	2	NULL
177	103	2022-06-09 05:04:04	5	NULL
178	4.30525286	2022-06-09 05:04:34	4	NULL
179	99	2022-06-09 05:05:04	5	NULL
180	41	2022-06-09 05:05:34	1	NULL
181	4.777294301	2022-06-09 05:06:04	4	NULL
182	12	2022-06-09 05:06:34	1	NULL
183	1	2022-06-09 05:07:04	2	NULL
184	1	2022-06-09 05:07:34	2	NULL
185	22	2022-06-09 05:08:04	6	NULL
186	69	2022-06-09 05:08:34	6	NULL
187	60	2022-06-09 05:09:04	6	NULL
188	100	2022-06-09 05:09:34	5	NULL
189	73	2022-06-09 05:10:04	6	NULL
190	30	2022-06-09 05:10:34	7	NULL
191	22	2022-06-09 05:11:04	7	NULL
192	112	2022-06-09 05:11:34	5	NULL
193	4.737113416	2022-06-09 05:12:04	4	NULL
194	71	2022-06-09 05:12:34	6	NULL
195	83	2022-06-09 05:13:04	5	NULL
196	42	2022-06-09 05:13:34	1	NULL
197	25	2022-06-09 05:14:04	7	NULL
198	79	2022-06-09 05:14:34	6	NULL
199	19	2022-06-09 05:15:04	1	NULL
200	62	2022-06-09 05:15:34	6	NULL
201	1	2022-06-09 05:16:04	2	NULL
202	25	2022-06-09 05:16:34	6	NULL
203	13	2022-06-09 05:17:04	1	NULL
204	83	2022-06-09 05:17:34	6	NULL
205	89	2022-06-09 05:18:04	5	NULL
206	59	2022-06-09 05:18:34	6	NULL
207	51.07588085	2022-06-09 05:19:04	3	NULL
208	29	2022-06-09 05:19:34	6	NULL
209	120	2022-06-09 05:20:04	5	NULL
210	98	2022-06-09 05:20:34	5	NULL
211	4.233305874	2022-06-09 05:21:04	4	NULL
212	113	2022-06-09 05:21:34	5	NULL
213	24	2022-06-09 05:22:04	7	NULL
214	50.69665406	2022-06-09 05:22:34	3	NULL
215	101	2022-06-09 05:23:04	5	NULL
216	15	2022-06-09 05:23:34	1	NULL
217	4.226930242	2022-06-09 05:24:04	4	NULL
218	1	2022-06-09 05:24:34	2	NULL
219	1	2022-06-09 05:25:04	2	NULL
220	1	2022-06-09 05:25:34	2	NULL
221	50.60825893	2022-06-09 05:26:04	3	NULL
222	16	2022-06-09 05:26:34	1	NULL
223	29	2022-06-09 05:27:04	7	NULL
224	50.8909638	2022-06-09 05:27:34	3	NULL
225	50.43073448	2022-06-09 05:28:04	3	NULL
226	29	2022-06-09 05:28:34	1	NULL
227	75	2022-06-09 05:29:04	6	NULL
228	19	2022-06-09 05:29:34	1	NULL
229	79	2022-06-09 05:30:04	6	NULL
230	25	2022-06-09 05:30:34	7	NULL
231	23	2022-06-09 05:31:04	6	NULL
232	84	2022-06-09 05:31:34	6	NULL
233	30	2022-06-09 05:32:04	7	NULL
234	102	2022-06-09 05:32:34	5	NULL
235	40	2022-06-09 05:33:04	6	NULL
236	95	2022-06-09 05:33:34	5	NULL
237	1	2022-06-09 05:34:04	2	NULL
238	4.881834842	2022-06-09 05:34:34	4	NULL
239	15	2022-06-09 05:35:04	1	NULL
240	25	2022-06-09 05:35:34	7	NULL
241	50.64640975	2022-06-09 05:36:04	3	NULL
242	4.026038027	2022-06-09 05:36:34	4	NULL
243	79	2022-06-09 05:37:04	6	NULL
244	80	2022-06-09 05:37:34	6	NULL
245	44	2022-06-09 05:38:04	6	NULL
246	50.82680233	2022-06-09 05:38:34	3	NULL
247	50.74630871	2022-06-09 05:39:04	3	NULL
248	4.879590867	2022-06-09 05:39:34	4	NULL
249	5	2022-06-09 05:40:04	1	NULL
250	50.52936205	2022-06-09 05:40:34	3	NULL
251	118	2022-06-09 05:41:04	5	NULL
252	32	2022-06-09 05:41:34	7	NULL
253	4.267328326	2022-06-09 05:42:04	4	NULL
254	30	2022-06-09 05:42:34	1	NULL
255	25	2022-06-09 05:43:04	7	NULL
256	4.779336196	2022-06-09 05:43:34	4	NULL
257	3.97538283	2022-06-09 05:44:04	4	NULL
258	99	2022-06-09 05:44:34	5	NULL
259	4.830581066	2022-06-09 05:45:04	4	NULL
260	28	2022-06-09 05:45:34	7	NULL
261	24	2022-06-09 05:46:04	6	NULL
262	1	2022-06-09 05:46:34	2	NULL
263	10	2022-06-09 05:47:04	1	NULL
264	1	2022-06-09 05:47:34	2	NULL
265	12	2022-06-09 05:48:04	1	NULL
266	1	2022-06-09 05:48:34	2	NULL
267	1	2022-06-09 05:49:04	2	NULL
268	93	2022-06-09 05:49:34	5	NULL
269	51.09125418	2022-06-09 05:50:04	3	NULL
270	4.074924527	2022-06-09 05:50:34	4	NULL
271	4.7702522	2022-06-09 05:51:04	4	NULL
272	30	2022-06-09 05:51:34	7	NULL
273	38	2022-06-09 05:52:04	1	NULL
274	29	2022-06-09 05:52:34	7	NULL
275	50.75249486	2022-06-09 05:53:04	3	NULL
276	1	2022-06-09 05:53:34	2	NULL
277	50.695703	2022-06-09 05:54:04	3	NULL
278	26	2022-06-09 05:54:34	1	NULL
279	50.62952951	2022-06-09 05:55:04	3	NULL
280	34	2022-06-09 05:55:34	6	NULL
281	1	2022-06-09 05:56:04	2	NULL
282	32	2022-06-09 05:56:34	1	NULL
283	50.94607192	2022-06-09 05:57:04	3	NULL
284	105	2022-06-09 05:57:34	5	NULL
285	1	2022-06-09 05:58:04	2	NULL
286	23	2022-06-09 05:58:34	7	NULL
287	3	2022-06-09 05:59:04	1	NULL
288	59	2022-06-09 05:59:34	6	NULL
289	32	2022-06-09 06:00:03	1	NULL
290	86	2022-06-09 06:00:33	6	NULL
291	1	2022-06-09 06:01:03	2	NULL
292	1	2022-06-09 06:01:33	2	NULL
293	103	2022-06-09 06:02:03	5	NULL
294	31	2022-06-09 06:02:33	7	NULL
295	119	2022-06-09 06:03:03	5	NULL
296	28	2022-06-09 06:03:33	7	NULL
297	21	2022-06-09 06:04:03	1	NULL
298	30	2022-06-09 06:04:33	7	NULL
299	6	2022-06-09 06:05:03	1	NULL
300	11	2022-06-09 06:05:33	1	NULL
301	50.95584961	2022-06-09 06:06:03	3	NULL
302	24	2022-06-09 06:06:33	7	NULL
303	1	2022-06-09 06:07:03	2	NULL
304	20	2022-06-09 06:07:33	1	NULL
305	27	2022-06-09 06:08:03	7	NULL
306	1	2022-06-09 06:08:33	1	NULL
307	51.24699888	2022-06-09 06:09:03	3	NULL
308	4.336553496	2022-06-09 06:09:33	4	NULL
309	1	2022-06-09 06:10:03	2	NULL
310	27	2022-06-09 06:10:33	7	NULL
311	26	2022-06-09 06:11:03	7	NULL
312	8	2022-06-09 06:11:33	1	NULL
313	36	2022-06-09 06:12:03	1	NULL
314	51.06202095	2022-06-09 06:12:33	3	NULL
315	1	2022-06-09 06:13:03	2	NULL
316	103	2022-06-09 06:13:33	5	NULL
317	28	2022-06-09 06:14:03	7	NULL
318	77	2022-06-09 06:14:33	6	NULL
319	1	2022-06-09 06:15:03	2	NULL
320	24	2022-06-09 06:15:33	7	NULL
321	4.053847251	2022-06-09 06:16:03	4	NULL
322	32	2022-06-09 06:16:33	7	NULL
323	5	2022-06-09 06:17:03	1	NULL
324	35	2022-06-09 06:17:33	1	NULL
325	94	2022-06-09 06:18:03	6	NULL
326	28	2022-06-09 06:18:33	7	NULL
327	29	2022-06-09 06:19:03	1	NULL
328	1	2022-06-09 06:19:33	2	NULL
329	4.68556257	2022-06-09 06:20:03	4	NULL
330	115	2022-06-09 06:20:33	5	NULL
331	87	2022-06-09 06:21:03	5	NULL
332	51.07211115	2022-06-09 06:21:33	3	NULL
333	95	2022-06-09 06:22:03	5	NULL
334	13	2022-06-09 06:22:33	1	NULL
335	50.57970822	2022-06-09 06:23:03	3	NULL
336	83	2022-06-09 06:23:33	5	NULL
337	50.63794355	2022-06-09 06:24:03	3	NULL
338	4.791679974	2022-06-09 06:24:33	4	NULL
339	1	2022-06-09 06:25:03	2	NULL
340	1	2022-06-09 06:25:33	2	NULL
341	43	2022-06-09 06:26:03	1	NULL
342	22	2022-06-09 06:26:33	7	NULL
343	31	2022-06-09 06:27:03	7	NULL
344	20	2022-06-09 06:27:33	1	NULL
345	32	2022-06-09 06:28:03	1	NULL
346	1	2022-06-09 06:28:33	2	NULL
347	24	2022-06-09 06:29:03	7	NULL
348	54	2022-06-09 06:29:33	6	NULL
349	51.14509826	2022-06-09 06:30:03	3	NULL
350	4.868955872	2022-06-09 06:30:33	4	NULL
351	72	2022-06-09 06:31:03	6	NULL
352	4.779414481	2022-06-09 06:31:33	4	NULL
353	1	2022-06-09 06:32:03	2	NULL
354	1	2022-06-09 06:32:33	2	NULL
355	1	2022-06-09 06:33:03	2	NULL
356	118	2022-06-09 06:33:33	5	NULL
357	4.731855182	2022-06-09 06:34:03	4	NULL
358	119	2022-06-09 06:34:33	5	NULL
359	50.57305249	2022-06-09 06:35:03	3	NULL
360	0	2022-06-09 06:35:33	1	NULL
361	1	2022-06-09 06:36:03	2	NULL
362	23	2022-06-09 06:36:33	7	NULL
363	44	2022-06-09 06:37:03	6	NULL
364	102	2022-06-09 06:37:33	5	NULL
365	4.607196654	2022-06-09 06:38:03	4	NULL
366	51.04005046	2022-06-09 06:38:33	3	NULL
367	17	2022-06-09 06:39:03	1	NULL
368	82	2022-06-09 06:39:33	5	NULL
369	31	2022-06-09 06:40:03	7	NULL
370	3	2022-06-09 06:40:33	1	NULL
371	3.928907379	2022-06-09 06:41:03	4	NULL
372	1	2022-06-09 06:41:33	2	NULL
373	1	2022-06-09 06:42:03	2	NULL
374	41	2022-06-09 06:42:33	1	NULL
375	109	2022-06-09 06:43:03	5	NULL
376	1	2022-06-09 06:43:33	2	NULL
377	1	2022-06-09 06:44:03	2	NULL
378	35	2022-06-09 06:44:33	1	NULL
379	4.754931246	2022-06-09 06:45:03	4	NULL
380	51.10884332	2022-06-09 06:45:33	3	NULL
381	29	2022-06-09 06:46:03	7	NULL
382	4.101052401	2022-06-09 06:46:33	4	NULL
383	4.536888268	2022-06-09 06:47:03	4	NULL
384	98	2022-06-09 06:47:33	6	NULL
385	26	2022-06-09 06:48:03	7	NULL
386	3.906974325	2022-06-09 06:48:33	4	NULL
387	28	2022-06-09 06:49:03	7	NULL
388	2	2022-06-09 06:49:33	1	NULL
389	1	2022-06-09 06:50:03	2	NULL
390	50.6392368	2022-06-09 06:50:33	3	NULL
391	112	2022-06-09 06:51:03	5	NULL
392	4.734217717	2022-06-09 06:51:33	4	NULL
393	23	2022-06-09 06:52:03	7	NULL
394	24	2022-06-09 06:52:33	7	NULL
395	99	2022-06-09 06:53:03	6	NULL
396	4.835879617	2022-06-09 06:53:33	4	NULL
397	28	2022-06-09 06:54:03	1	NULL
398	24	2022-06-09 06:54:33	7	NULL
399	38	2022-06-09 06:55:03	6	NULL
400	30	2022-06-09 06:55:33	6	NULL
401	62	2022-06-09 06:56:03	6	NULL
402	4.55657032	2022-06-09 06:56:33	4	NULL
403	1	2022-06-09 06:57:03	2	NULL
404	113	2022-06-09 06:57:33	5	NULL
405	1	2022-06-09 06:58:03	2	NULL
406	60	2022-06-09 06:58:33	6	NULL
407	24	2022-06-09 06:59:03	7	NULL
408	64	2022-06-09 06:59:33	6	NULL
409	4.828240436	2022-06-09 07:00:03	4	NULL
410	26	2022-06-09 07:00:33	1	NULL
411	1	2022-06-09 07:01:03	2	NULL
412	91	2022-06-09 07:01:33	5	NULL
413	41	2022-06-09 07:02:03	1	NULL
414	115	2022-06-09 07:02:33	5	NULL
415	29	2022-06-09 07:03:03	7	NULL
416	51.07081467	2022-06-09 07:03:33	3	NULL
417	120	2022-06-09 07:04:03	5	NULL
418	36	2022-06-09 07:04:33	1	NULL
419	22	2022-06-09 07:05:03	7	NULL
420	1	2022-06-09 07:05:33	2	NULL
421	4.378018997	2022-06-09 07:06:03	4	NULL
422	1	2022-06-09 07:06:33	2	NULL
423	4.672114366	2022-06-09 07:07:03	4	NULL
424	1	2022-06-09 07:07:33	2	NULL
425	31	2022-06-09 07:08:03	7	NULL
426	91	2022-06-09 07:08:33	5	NULL
427	92	2022-06-09 07:09:03	6	NULL
428	82	2022-06-09 07:09:33	5	NULL
429	23	2022-06-09 07:10:03	7	NULL
430	51.07835478	2022-06-09 07:10:33	3	NULL
431	41	2022-06-09 07:11:03	1	NULL
432	40	2022-06-09 07:11:33	6	NULL
433	51.25875855	2022-06-09 07:12:03	3	NULL
434	4.538516303	2022-06-09 07:12:33	4	NULL
435	50	2022-06-09 07:13:03	6	NULL
436	50.79510078	2022-06-09 07:13:33	3	NULL
437	4.630413613	2022-06-09 07:14:03	4	NULL
438	3.908335777	2022-06-09 07:14:33	4	NULL
439	16	2022-06-09 07:15:03	1	NULL
440	1	2022-06-09 07:15:33	2	NULL
441	93	2022-06-09 07:16:03	5	NULL
442	1	2022-06-09 07:16:33	2	NULL
443	49	2022-06-09 07:17:03	6	NULL
444	1	2022-06-09 07:17:33	2	NULL
445	84	2022-06-09 07:18:03	5	NULL
446	25	2022-06-09 07:18:33	7	NULL
447	117	2022-06-09 07:19:03	5	NULL
448	86	2022-06-09 07:19:33	5	NULL
449	5	2022-06-09 07:20:03	1	NULL
450	4.119738779	2022-06-09 07:20:33	4	NULL
451	31	2022-06-09 07:21:03	7	NULL
452	31	2022-06-09 07:21:33	6	NULL
453	53	2022-06-09 07:22:03	6	NULL
454	8	2022-06-09 07:22:33	1	NULL
455	4.139285673	2022-06-09 07:23:03	4	NULL
456	1	2022-06-09 07:23:33	2	NULL
457	4.000729963	2022-06-09 07:24:03	4	NULL
458	50.32867688	2022-06-09 07:24:33	3	NULL
459	1	2022-06-09 07:25:03	2	NULL
460	35	2022-06-09 07:25:33	1	NULL
461	80	2022-06-09 07:26:03	5	NULL
462	50.41611906	2022-06-09 07:26:33	3	NULL
463	82	2022-06-09 07:27:03	5	NULL
464	36	2022-06-09 07:27:33	1	NULL
465	50.56515446	2022-06-09 07:28:03	3	NULL
466	94	2022-06-09 07:28:33	5	NULL
467	30	2022-06-09 07:29:03	6	NULL
468	23	2022-06-09 07:29:33	1	NULL
469	4.083196454	2022-06-09 07:30:03	4	NULL
470	31	2022-06-09 07:30:33	7	NULL
471	27	2022-06-09 07:31:03	7	NULL
472	24	2022-06-09 07:31:33	7	NULL
473	29	2022-06-09 07:32:03	1	NULL
474	15	2022-06-09 07:32:33	1	NULL
475	1	2022-06-09 07:33:03	2	NULL
476	1	2022-06-09 07:33:33	2	NULL
477	1	2022-06-09 07:34:03	2	NULL
478	8	2022-06-09 07:34:33	1	NULL
479	45	2022-06-09 07:35:03	6	NULL
480	116	2022-06-09 07:35:33	5	NULL
481	4.549719285	2022-06-09 07:36:03	4	NULL
482	50.37777797	2022-06-09 07:36:33	3	NULL
483	50.77508407	2022-06-09 07:37:03	3	NULL
484	1	2022-06-09 07:37:33	2	NULL
485	3	2022-06-09 07:38:03	1	NULL
486	27	2022-06-09 07:38:33	1	NULL
487	50.35573022	2022-06-09 07:39:03	3	NULL
488	30	2022-06-09 07:39:33	7	NULL
489	4.238985103	2022-06-09 07:40:02	4	NULL
490	50.3357893	2022-06-09 07:40:32	3	NULL
491	94	2022-06-09 07:41:02	6	NULL
492	50.7375723	2022-06-09 07:41:32	3	NULL
493	50.77369341	2022-06-09 07:42:02	3	NULL
494	97	2022-06-09 07:42:32	5	NULL
495	1	2022-06-09 07:43:02	2	NULL
496	3.937662666	2022-06-09 07:43:32	4	NULL
497	105	2022-06-09 07:44:02	5	NULL
498	1	2022-06-09 07:44:32	2	NULL
499	113	2022-06-09 07:45:02	5	NULL
500	1	2022-06-09 07:45:32	2	NULL
501	89	2022-06-09 07:46:02	6	NULL
502	28	2022-06-09 07:46:32	7	NULL
503	49	2022-06-09 07:47:02	6	NULL
504	36	2022-06-09 07:47:32	6	NULL
505	60	2022-06-09 07:48:02	6	NULL
506	65	2022-06-09 07:48:32	6	NULL
507	105	2022-06-09 07:49:02	5	NULL
508	4.314553682	2022-06-09 07:49:32	4	NULL
509	17	2022-06-09 07:50:02	1	NULL
510	87	2022-06-09 07:50:32	5	NULL
511	23	2022-06-09 07:51:02	7	NULL
512	1	2022-06-09 07:51:32	2	NULL
513	32	2022-06-09 07:52:02	7	NULL
514	4.322850733	2022-06-09 07:52:32	4	NULL
515	1	2022-06-09 07:53:02	2	NULL
516	89	2022-06-09 07:53:32	5	NULL
517	58	2022-06-09 07:54:02	6	NULL
518	32	2022-06-09 07:54:32	7	NULL
519	108	2022-06-09 07:55:02	5	NULL
520	50.39099253	2022-06-09 07:55:32	3	NULL
521	1	2022-06-09 07:56:02	2	NULL
522	62	2022-06-09 07:56:32	6	NULL
523	51.06708572	2022-06-09 07:57:02	3	NULL
524	4.265884094	2022-06-09 07:57:32	4	NULL
525	4.816643665	2022-06-09 07:58:02	4	NULL
526	33	2022-06-09 07:58:32	1	NULL
527	22	2022-06-09 07:59:02	7	NULL
528	29	2022-06-09 07:59:32	7	NULL
529	29	2022-06-09 08:00:02	1	NULL
530	25	2022-06-09 08:00:32	7	NULL
531	119	2022-06-09 08:01:02	5	NULL
532	1	2022-06-09 08:01:32	2	NULL
533	3.990156817	2022-06-09 08:02:02	4	NULL
534	102	2022-06-09 08:02:32	5	NULL
535	19	2022-06-09 08:03:02	1	NULL
536	1	2022-06-09 08:03:32	2	NULL
537	1	2022-06-09 08:04:02	2	NULL
538	60	2022-06-09 08:04:32	6	NULL
539	80	2022-06-09 08:05:02	5	NULL
540	85	2022-06-09 08:05:32	6	NULL
541	4.245985057	2022-06-09 08:06:02	4	NULL
542	25	2022-06-09 08:06:32	7	NULL
543	87	2022-06-09 08:07:02	5	NULL
544	1	2022-06-09 08:07:32	2	NULL
545	3.995648729	2022-06-09 08:08:02	4	NULL
546	50.40402454	2022-06-09 08:08:32	3	NULL
547	3.935870025	2022-06-09 08:09:02	4	NULL
548	44	2022-06-09 08:09:32	1	NULL
549	85	2022-06-09 08:10:02	6	NULL
550	4.705924679	2022-06-09 08:10:32	4	NULL
551	26	2022-06-09 08:11:02	7	NULL
552	16	2022-06-09 08:11:32	1	NULL
553	1	2022-06-09 08:12:02	2	NULL
554	50.32997868	2022-06-09 08:12:32	3	NULL
555	1	2022-06-09 08:13:02	2	NULL
556	4.547926316	2022-06-09 08:13:32	4	NULL
557	34	2022-06-09 08:14:02	1	NULL
558	51.0610688	2022-06-09 08:14:32	3	NULL
559	50.83646868	2022-06-09 08:15:02	3	NULL
560	1	2022-06-09 08:15:32	2	NULL
561	1	2022-06-09 08:16:02	2	NULL
562	50.41782526	2022-06-09 08:16:32	3	NULL
563	51.11576767	2022-06-09 08:17:02	3	NULL
564	50.83864566	2022-06-09 08:17:32	3	NULL
565	4.670721225	2022-06-09 08:18:02	4	NULL
566	74	2022-06-09 08:18:32	6	NULL
567	37	2022-06-09 08:19:02	6	NULL
568	50.51695526	2022-06-09 08:19:32	3	NULL
569	4.503959082	2022-06-09 08:20:02	4	NULL
570	67	2022-06-09 08:20:32	6	NULL
571	3.967619017	2022-06-09 08:21:02	4	NULL
572	3	2022-06-09 08:21:32	1	NULL
573	1	2022-06-09 08:22:02	2	NULL
574	25	2022-06-09 08:22:32	6	NULL
575	4.097312459	2022-06-09 08:23:02	4	NULL
576	95	2022-06-09 08:23:32	5	NULL
577	50.86849622	2022-06-09 08:24:02	3	NULL
578	84	2022-06-09 08:24:32	5	NULL
579	50.86764128	2022-06-09 08:25:02	3	NULL
580	106	2022-06-09 08:25:32	5	NULL
581	26	2022-06-09 08:26:02	7	NULL
582	1	2022-06-09 08:26:32	2	NULL
583	87	2022-06-09 08:27:02	5	NULL
584	26	2022-06-09 08:27:32	7	NULL
585	1	2022-06-09 08:28:02	2	NULL
586	50.422627	2022-06-09 08:28:32	3	NULL
587	23	2022-06-09 08:29:02	7	NULL
588	104	2022-06-09 08:29:32	5	NULL
589	120	2022-06-09 08:30:02	5	NULL
590	12	2022-06-09 08:30:32	1	NULL
591	46	2022-06-10 07:40:32	6	NULL
592	3.906598849	2022-06-10 07:41:02	4	NULL
593	1	2022-06-10 07:41:32	2	NULL
594	45	2022-06-10 07:42:02	6	NULL
595	24	2022-06-10 07:42:32	7	NULL
596	41	2022-06-10 07:43:02	1	NULL
597	102	2022-06-10 07:43:32	5	NULL
598	50.63712743	2022-06-10 07:44:02	3	NULL
599	37	2022-06-10 07:44:32	1	NULL
600	27	2022-06-10 07:45:02	1	NULL
601	4.739154549	2022-06-10 07:45:32	4	NULL
602	16	2022-06-10 07:46:02	1	NULL
603	108	2022-06-10 07:46:32	5	NULL
604	4.103769806	2022-06-10 07:47:02	4	NULL
605	25	2022-06-10 07:47:32	7	NULL
606	4.409422768	2022-06-10 07:48:02	4	NULL
607	88	2022-06-10 07:48:32	5	NULL
608	58	2022-06-10 07:49:02	6	NULL
609	90	2022-06-10 07:49:32	5	NULL
610	35	2022-06-10 07:50:02	6	NULL
611	47	2022-06-10 07:50:32	6	NULL
612	4.420218612	2022-06-10 07:51:02	4	NULL
613	3.970183903	2022-06-10 07:51:32	4	NULL
614	4.28601983	2022-06-10 07:52:02	4	NULL
615	9	2022-06-10 07:52:32	1	NULL
616	42	2022-06-10 07:53:02	1	NULL
617	94	2022-06-10 07:53:32	5	NULL
618	96	2022-06-10 07:54:02	6	NULL
619	43	2022-06-10 07:54:32	1	NULL
620	51.2181421	2022-06-10 07:55:02	3	NULL
621	99	2022-06-10 07:55:32	6	NULL
622	81	2022-06-10 07:56:02	5	NULL
623	60	2022-06-10 07:56:32	6	NULL
624	50.41318412	2022-06-10 07:57:02	3	NULL
625	32	2022-06-10 07:57:32	7	NULL
626	23	2022-06-10 07:58:02	1	NULL
627	23	2022-06-10 07:58:32	7	NULL
628	72	2022-06-10 07:59:02	6	NULL
629	105	2022-06-10 07:59:32	5	NULL
630	1	2022-06-10 08:00:02	2	NULL
631	24	2022-06-10 08:00:32	7	NULL
632	1	2022-06-10 08:01:02	2	NULL
633	4.287482224	2022-06-10 08:01:32	4	NULL
634	4.817544498	2022-06-10 08:02:02	4	NULL
635	1	2022-06-10 08:02:32	2	NULL
636	2	2022-06-10 08:03:02	1	NULL
637	1	2022-06-10 08:03:32	2	NULL
638	46	2022-06-10 08:04:02	1	NULL
639	26	2022-06-10 08:04:32	6	NULL
640	1	2022-06-10 08:05:02	2	NULL
641	1	2022-06-10 08:05:32	2	NULL
642	3.953752282	2022-06-10 08:06:02	4	NULL
643	30	2022-06-10 08:06:32	7	NULL
644	11	2022-06-10 08:07:02	1	NULL
645	30	2022-06-10 08:07:32	7	NULL
646	50.7251474	2022-06-10 08:08:02	3	NULL
647	93	2022-06-10 08:08:32	5	NULL
648	50.52792314	2022-06-10 08:09:02	3	NULL
649	40	2022-06-10 08:09:32	1	NULL
650	50.31428945	2022-06-10 08:10:02	3	NULL
651	1	2022-06-10 08:10:32	2	NULL
652	4.077016754	2022-06-10 08:11:02	4	NULL
653	50.6253278	2022-06-10 08:11:32	3	NULL
654	55	2022-06-10 08:12:02	6	NULL
655	50.35146764	2022-06-10 08:12:32	3	NULL
656	1	2022-06-10 08:13:02	2	NULL
657	1	2022-06-10 08:13:32	2	NULL
658	4.580266167	2022-06-10 08:14:02	4	NULL
659	1	2022-06-10 08:14:32	2	NULL
660	50.9640858	2022-06-10 08:15:02	3	NULL
661	4.423320679	2022-06-10 08:15:32	4	NULL
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

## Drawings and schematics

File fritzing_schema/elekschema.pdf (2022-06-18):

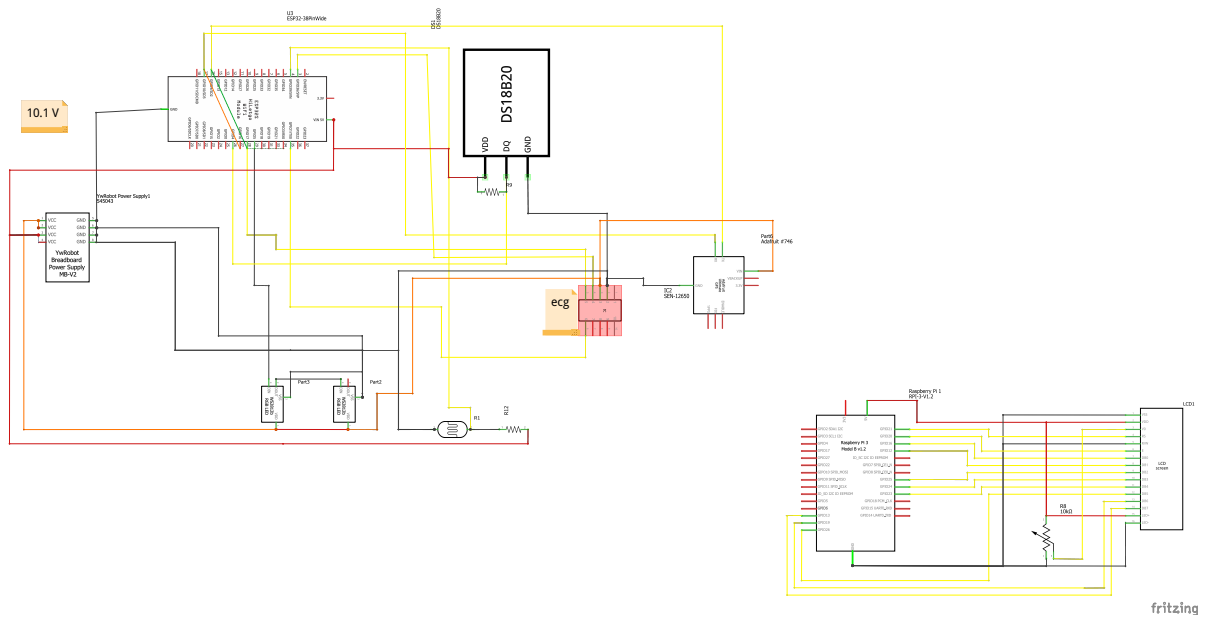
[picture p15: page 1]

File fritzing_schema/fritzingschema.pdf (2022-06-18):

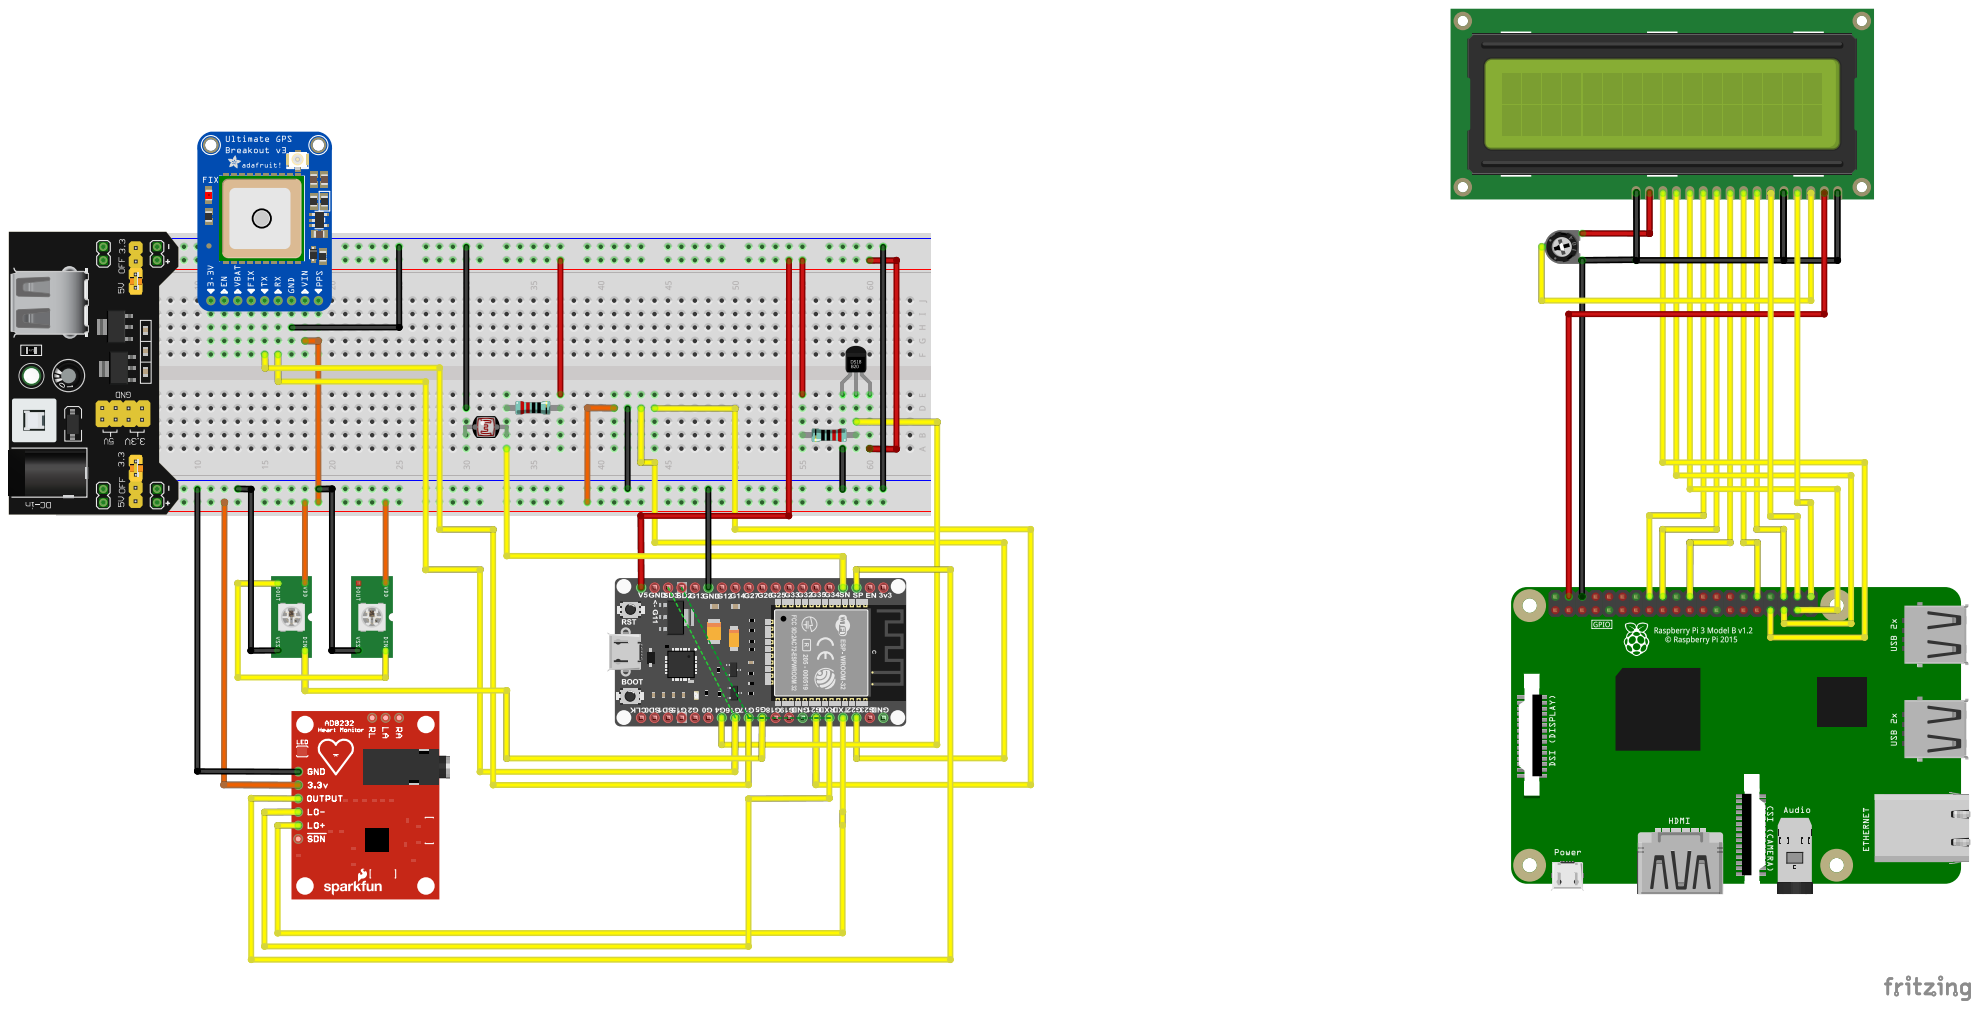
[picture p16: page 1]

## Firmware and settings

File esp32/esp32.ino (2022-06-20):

// #include <WiFi.h>
#include <Wire.h>
#include <OneWire.h>
#include <BluetoothSerial.h>
#include <FastLED.h>

#define numLeds 12

CRGBArray<numLeds> leds;

byte i; // led intensity
byte pinWS2812 = 13;
int hue = 360;
String recvd_hue = "";
String strHue;

// timed events
// measure temperature/light intensity
int eventtimeTemp = 30000;
int pasteventTemp = 0;
//
byte LOplus = 41;
byte LOmin = 40;
const byte owTemp = 4;
float hoek;
bool tussenStap2 = 0;
byte stappen = 0;
int ldrPin = 34;
float lightValue;
float pastLightValue = 9999.0;
const int MPU = 0x68; // MPU6050 I2C address
int GyroY;
// bools
bool ledStatus = 0;
//
// ecg
int heartVal;
int pastHeartVal;
long startTime = millis();
long endTime = 0;
float pulse;
//

OneWire ds(owTemp);

BluetoothSerial SerialBT;

#define GPSSerial Serial2

void setup()
{
  // ecg
  pinMode(LOplus, INPUT);
  pinMode(LOmin, INPUT);
  //
  FastLED.addLeds<NEOPIXEL, 13>(leds, numLeds);
  // basic setup
  byte LED = 2;
  pinMode(LED, OUTPUT);

  Serial.begin(115200);

  // wifi setup
  // WiFi.begin(ssid, password);
  // BT setup
  SerialBT.begin("DogBit-BD-1MCT1");

  //# region MPU setup

  Wire.begin(); // Initialize comunication
  mpuWriteMsg(0x6B, 0x1);
  mpuWriteMsg(0x1c, 0x10);
  mpuWriteMsg(0x1B, 0x10);
  delay(20);

  GPSSerial.begin(9600);
  sendTemperature();
  getGPSdata();
}

void loop()
{
  // show loop is running
  digitalWrite(2, 1);
  delay(10);
  digitalWrite(2, 0);
  // //

  // elke 30 seconden wordt de temperatuur en licht intensiteit doorgestuurd
  if ((millis() - pasteventTemp) > eventtimeTemp)
  {
    sendTemperature();
    pasteventTemp = millis();
    getLightIntensity();
    stappen = 0;
    Serial.println(stappen);
    getGPSdata();
  }
  if (stappen >= 50)
  {
    stappen = 0;
    Serial.println(stappen);
    getGPSdata();
  }

  setLedIntensity();
  detectSteps();
  setLedColor();
}

void sendTemperature()
{
  byte i;
  byte type_s;
  byte data[12];
  byte addr[8];
  float temperatureC;

  if (!ds.search(addr))
  {
    ds.reset_search();
    return;
  }

  if (OneWire::crc8(addr, 7) != addr[7])
  {
    return;
  }

  // the first ROM byte indicates which chip
  ds.reset();
  ds.select(addr);
  ds.write(0x44);

  ds.reset();
  ds.select(addr);
  ds.write(0xBE);

  for (i = 0; i < 9; i++)
  {
    data[i] = ds.read();
  }

  int16_t raw = (data[1] << 8) | data[0];
  if (type_s)
  {
    raw = raw << 3;
    if (data[7] == 0x10)
    {
      raw = (raw & 0xFFF0) + 12 - data[6];
    }
  }
  else
  {
    byte cfg = (data[4] & 0x60);
    if (cfg == 0x00)
      raw = raw & ~7;
    else if (cfg == 0x20)
      raw = raw & ~3;
    else if (cfg == 0x40)
      raw = raw & ~1;
  }
  temperatureC = (float)raw / 16.0;
  SerialBT.println("temperatuur: " + String(temperatureC));
}

// #region step counter
void mpuWriteMsg(int regAdres, int msg)
{
  Wire.beginTransmission(MPU);
  Wire.write(regAdres);
  Wire.write(msg);
  Wire.endTransmission(true);
}

void mpuDataRequest(int regAdres, int bytes)
{
  Wire.beginTransmission(MPU);
  Wire.write(regAdres);
  Wire.endTransmission(false);
  Wire.requestFrom(MPU, bytes, true);
}

void detectSteps()
{
  mpuDataRequest(0x45, 6);
  GyroY = (Wire.read() << 8 | Wire.read());
  if (((GyroY & 0x8000) >> 15) == 1)
  {
    hoek = (GyroY - 0xffff) / 131.0;
  }
  else
  {
    hoek = GyroY / 131.0;
  }

  float corner = 12.22;
  /* Get new sensor events with the readings */

  // code for step counter
  if (hoek < (-1 * corner))
  {
    tussenStap2 = 1;
  }

  if ((hoek > corner) && (tussenStap2 == 1))
  {
    tussenStap2 = 0;
    stappen += 1;
    SerialBT.println("\nstappen +1");
  }
}
//

void getGPSdata()
{
  while ((Serial.available()) or (GPSSerial.available()))
  {
    while (Serial.available())
    {
      char c = Serial.read();
      GPSSerial.write(c);
    }
    while (GPSSerial.available())
    {
      char c = GPSSerial.read();
      Serial.write(c);
      SerialBT.print(c);
    }
  }
}

void getLightIntensity()
{
  lightValue = analogRead(ldrPin);
  SerialBT.println("LI: " + String((lightValue / 4095) * 100));
}

void setLedIntensity()
{
  lightValue = ((analogRead(ldrPin) / 4095.0) * 100.0);
  // Serial.println(analogRead(ldrPin));

  if (lightValue <= 75)
  {
    if (abs(lightValue - pastLightValue) > 15)
    {
      pastLightValue = lightValue * 1.0; // *1.0 zodat het zeker float blijft
      i = ((100 - lightValue) / 100) * 255;
      if (strHue == "pride")
      {
        setWhite(i);
      }
      else if (strHue == "white")
      {
        setRainbow(i);
      }
      else
      {
        setSingleColor(i);
      }
      SerialBT.println("LEDSTATUS=ON");
    }
  }

  else if (ledStatus)
  {
    pastLightValue = 85.0;
    for (byte j = 0; j < numLeds; j++)
    {
      leds[j] = CHSV(0, 0, 0);
      ;
    }
    FastLED.show();
    SerialBT.println("LEDSTATUS=OFF");
    ledStatus = 0;
  }
}

void setLedColor()
{
  while (SerialBT.available())
  {
    // Serial.println("ontvangen");
    // Serial.write(SerialBT.read());
    pastLightValue = -1000;
    char c = SerialBT.read();
    recvd_hue += c;
    // Serial.write(c);
  }
  if (recvd_hue != "")
  {
    strHue = "";
    for (byte i = 5; i <= 9; i++)
    {
      strHue += recvd_hue[i];
      hue = strHue.toInt();
      // Serial.println("strhue " + strHue);
      // Serial.println("hue " + String(hue));
      // Serial.println(recvd_hue[i]);
      // Serial.println(strHue);
    }
  }
  recvd_hue = "";
}

void measureECG()
{
  if ((digitalRead(LOplus) == 1) || (digitalRead(LOmin) == 1))
  {
    Serial.println('!');
  }
  else
  {
    heartVal = analogRead(A0);
    //        Serial.println(heartVal);
    if (heartVal > 2500)
    {
      heartVal = analogRead(A0);
      if (heartVal < pastHeartVal)
      {
        if (endTime != startTime)
        {
          pulse = 300 / ((startTime - endTime) / (200.0));
          //          Serial.println(pulse);
          SerialBT.println("pulse: " + String(pulse));
        }
      }
      pastHeartVal = heartVal;
      endTime = startTime;
    }
    else
    {
      startTime = millis();
    }
  }
}

void setRainbow(int p_sat)
{
  int rainbowColors[numLeds] = {354, 354, 34, 34, 60, 60, 131, 131, 240, 240, 304, 304};
  float subcalc;
  int hueColor;
  for (byte j = 0; j < numLeds; j++)
  {
    subcalc = rainbowColors[j] / 360.0;
    hueColor = subcalc * 255;
    Serial.println(hueColor);
    leds[j] = CHSV(hueColor, 255, p_sat);
  }
  FastLED.show();
}

void setSingleColor(int p_sat)
{
  for (byte j = 0; j < numLeds; j++)
  {
    leds[j] = CHSV(hue, 255, p_sat);
  }
  FastLED.show();
}

void setWhite(int p_bright)
{
  for (byte j = 0; j < numLeds; j++)
  {
    leds[j] = CRGB(p_bright, p_bright, p_bright);
  }
  FastLED.show();
}

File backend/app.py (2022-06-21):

import time
from RPi import GPIO
from helpers.klasseknop import Button
import threading
# print(__name__, time.now())
from flask_cors import CORS
from flask_socketio import SocketIO, emit, send
from flask import Flask, jsonify
from repositories.DataRepository import DataRepository

from klasses.SerCom import SerCom
from klasses.BTconfig import BTconfig
from klasses.PA1616s import PA1616s
from klasses.LCD import LCDcontrol

from selenium import webdriver
from datetime import datetime
import os
from subprocess import check_output

# from selenium import webdriver
# from selenium.webdriver.chrome.options import Options


channel = "hci0"
mac = "78:21:84:7D:85:BE"

    

def connect_to_esp32():
    global DogBit
    print('connecting to BT...')
    BT = BTconfig(channel, mac)
    time.sleep(2)
    while 1:
        try:
            BT.open_connection()
            time.sleep(2)
            DogBit = SerCom("rfcomm0")
            break
            
        except:
            # print('.')
            pass
    # return DogBit

DogBit = None
status_led = 'start'
fix = 0


# Code voor Flask
app = Flask(__name__)
app.config['SECRET_KEY'] = 'geheim!'
socketio = SocketIO(app, cors_allowed_origins="*", logger=False,
                    engineio_logger=False, ping_timeout=1)

CORS(app)


@socketio.on_error()        # Handles the default namespace
def error_handler(e):
    print("error: ", e)

# API ENDPOINTS
endpoint = '/api/v1/'
@app.route('/')
def hallo():
    return "Server is running, er zijn momenteel geen API endpoints beschikbaar."



@app.route(endpoint+'/historiek/day/', methods=['GET'])
def dag_historiek():
    data = DataRepository.get_historiek_day()
    data_to_send = []
    
    stappen = {}
    speed = {}
    temp = {}
    heartrate = {}
    print('sending data to client')
    for eenheid in data:
        e_id = eenheid['eenheidid']
        x = datetime.fromtimestamp(eenheid['x']/1000)
        x = x.strftime('%x %H')


        if (e_id == 1):
            if (x in speed.keys()):
                speed[x].append(float(eenheid['y']))

            elif (x not in speed.keys()): 
                speed[x] = [float(eenheid['y'])]

        
        elif (e_id == 2):
            if (x in stappen.keys()):
                stappen[x] += int(eenheid['y'])

            elif (x not in stappen.keys()): 
                stappen[x] = int(eenheid['y'])

        elif (e_id == 5):
            if (x in heartrate.keys()):
                heartrate[x].append(float(eenheid['y']))

            elif (x not in heartrate.keys()): 
                heartrate[x] = [float(eenheid['y'])]
        
        elif (e_id == 7):
            if (x in temp.keys()):
                temp[x].append(float(eenheid['y']))

            elif (x not in temp.keys()): 
                temp[x] = [float(eenheid['y'])]
    # making viable data
    print('...')
    for i in stappen:
        x = datetime.timestamp(datetime.strptime(i+':00:00', '%x %X'))*1000
        data_to_send.append({'eenheidid': 2, 'x':x, 'y': stappen[i]})   
    
    for i in temp:
        # print('temp', i)
        x = datetime.timestamp(datetime.strptime(i+':00:00', '%x %X'))*1000
        data_to_send.append({'eenheidid': 7, 'x':x, 'y': sum(temp[i])/len(temp[i])}) 

    for i in speed:
        x = datetime.timestamp(datetime.strptime(i+':00:00', '%x %X'))*1000
        data_to_send.append({'eenheidid': 1, 'x':x, 'y': sum(speed[i])/len(speed[i])})   
    
    for i in heartrate:
        x = datetime.timestamp(datetime.strptime(i+':00:00', '%x %X'))*1000
        data_to_send.append({'eenheidid': 1, 'x':x, 'y': sum(heartrate[i])/len(heartrate[i])})   
    
    print(jsonify(data_to_send))        

    print('data sent to client')
    return jsonify(data_to_send)

@app.route(endpoint+'/historiek/week/', methods=['GET'])
def week_historiek():
    data = DataRepository.get_historiek_week()
    data_to_send = []
    
    stappen = {}
    speed = {}
    temp = {}
    heartrate = {}
    print('sending data to client')
    for eenheid in data:
        e_id = eenheid['eenheidid']
        x = datetime.fromtimestamp(eenheid['x']/1000)
        x = x.strftime('%x')


        if (e_id == 1):
            if (x in speed.keys()):
                speed[x].append(float(eenheid['y']))

            elif (x not in speed.keys()): 
                speed[x] = [float(eenheid['y'])]

        
        elif (e_id == 2):
            if (x in stappen.keys()):
                stappen[x] += int(eenheid['y'])

            elif (x not in stappen.keys()): 
                stappen[x] = int(eenheid['y'])

        elif (e_id == 5):
            if (x in heartrate.keys()):
                heartrate[x].append(float(eenheid['y']))

            elif (x not in heartrate.keys()): 
                heartrate[x] = [float(eenheid['y'])]
        
        elif (e_id == 7):
            if (x in temp.keys()):
                temp[x].append(float(eenheid['y']))

            elif (x not in temp.keys()): 
                temp[x] = [float(eenheid['y'])]

    # making viable data
    print('...')
    for i in stappen:
        x = datetime.timestamp(datetime.strptime(i, '%x'))*1000
        data_to_send.append({'eenheidid': 2, 'x':x, 'y': stappen[i]})   
    
    for i in temp:
        # print('temp', i)
        x = datetime.timestamp(datetime.strptime(i, '%x'))*1000
        data_to_send.append({'eenheidid': 7, 'x':x, 'y': sum(temp[i])/len(temp[i])}) 

    for i in speed:
        x = datetime.timestamp(datetime.strptime(i, '%x'))*1000
        data_to_send.append({'eenheidid': 1, 'x':x, 'y': sum(speed[i])/len(speed[i])})   
    
    for i in heartrate:
        x = datetime.timestamp(datetime.strptime(i, '%x'))*1000
        data_to_send.append({'eenheidid': 5, 'x':x, 'y': sum(heartrate[i])/len(heartrate[i])})   
    
    print(jsonify(data_to_send))        

    print('data sent to client')
    return jsonify(data_to_send)
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

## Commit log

2022-05-24 code voor esp32 toegevoegd
2022-05-24 commit 2: sneller uitlezen mpu, om beter een stappen teller te kunnen maken
2022-05-24 issue-2: stappen worden juist geteld
    [esp32.ino]
2022-05-25 commit: temperatuur niet langer invasief, stappenteller te gevoelig?
2022-05-30 verkeerde issue: LDR en LEDs afstellen
    [ecg-test.ino, measure_temp.ino]
2022-05-31 issue 04: al een tijdje afgerond i know
    [esp32.ino]
2022-06-08 fix: data word juist gegrouped voor hue
    [esp32.ino]
2022-06-09 feature: hue kan aangepast worden fix: hue wordt ook aangepast wanneer leds aanstaan
    [esp32.ino]
2022-06-18 add: added necessary files
    [doos v26.3mf]
2022-06-20 fix: ip adress shows at startup
    [app.py]
2022-06-20 fix: ip shows on startup
    [LCD.py, app.py]
2022-06-20 fix: making it possible again for presets to be saved in db
    [app.py, esp32.ino]
2022-06-20 fix: veschoven lijntje teruggeplaats
    [app.py]
2022-06-21 fix: led hue update bug
    [app.py]
